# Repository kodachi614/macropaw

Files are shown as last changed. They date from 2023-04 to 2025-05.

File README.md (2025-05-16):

# MacroPaw Keypads

The MacroPaw keypads are a line of small yet fully-customizable mechanical
keyboards. (The name was originally from my son, years ago when he was young,
and the "paw" motif has kinda stuck.) The core of the MacroPaws is a Raspberry
Pi RP2040 with 16MiB of flash memory, a USB-C connector, and an attached key
matrix and RGB LEDs (which may or may not be under the keys). Some MacroPaws
have more capability than others; all are crazy customizable by writing Python
code. (Yes. Python. On a keyboard. It's insane and wonderful to live in the
future.)

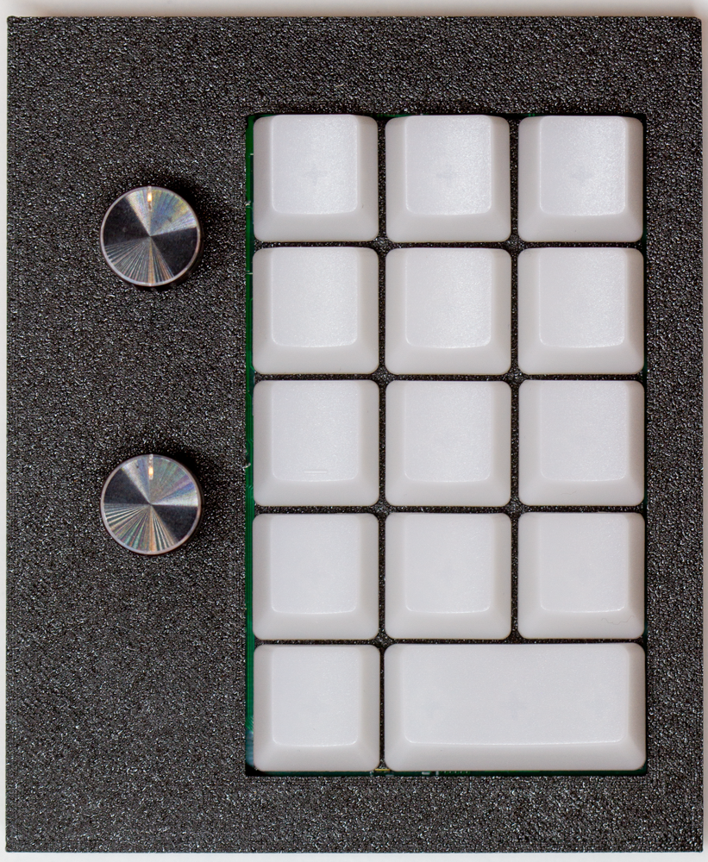
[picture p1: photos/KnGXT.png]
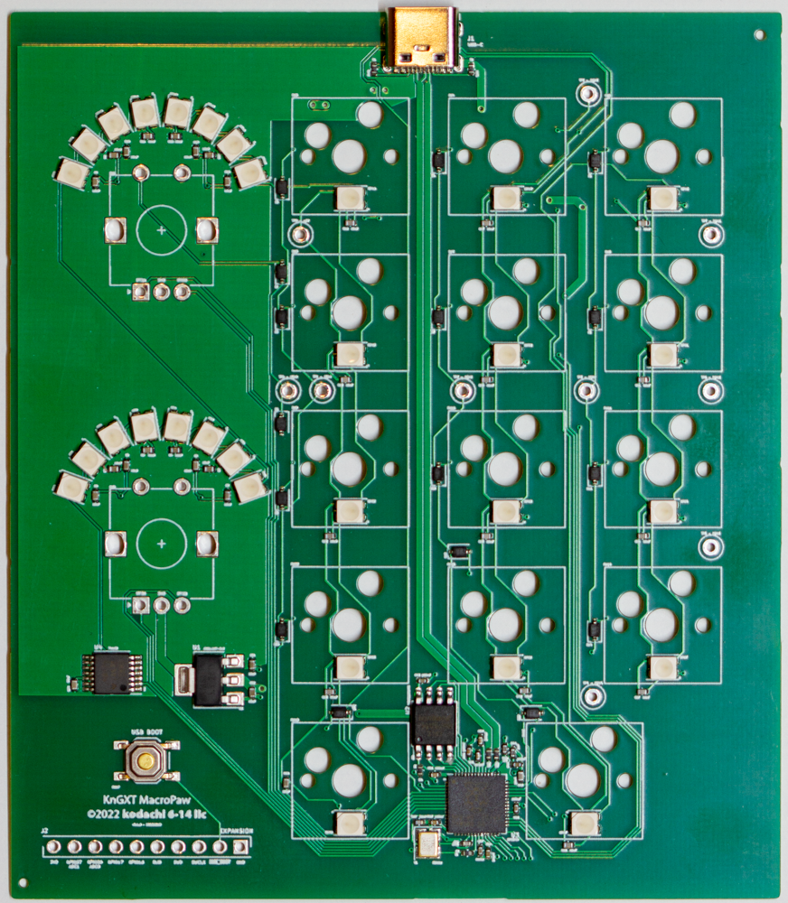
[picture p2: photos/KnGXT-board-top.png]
|  |  |
| :-: | :-: |
| _Assembled KnGXT_ | _KnGXT PCB_ |

Currently extant MacroPaw boards include:

| Board ID | Description |
| :-: | :- |
| KnGXT | Mostly a proof-of-concept for an RP2040-based USB HID: it has 14 hotswappable MX keyswitches in a 3x5 layout like a number pad (including one 2U key, which is why it's 14 instead of 15), two rotary encoders with pushbuttons, and a bunch of RGB LEDs under the encoders and keys. |
| KnGYT | Mostly a proof-of-concept for double-sided assembly. It has ten hotswappable MX keyswitches in a 5x2 grid, ten RGB LEDs under the keys, and no rotary encoders. It's _much_ smaller than its sibling the KnGXT, because most of the electronics are on the back of the board. |
| Beatboxer KnH0F | A single-sided embedded keyboard controller for use in a [custom life-sized drum machine]. It has 8 RGB LEDs on the front of the board for hardware test and debugging, and its key matrix is an 8x8 grid that's mechanically arranged as a 16x4 grid of arcade buttons. |

[custom life-sized drum machine]: https://sig.gy/bbox/

Both the firmware and the hardware of the MacroPaws are **open source**.

## Firmware

The firmware is licensed under the GNU General Public License, version 3.0 or
later.

The `firmware` directory within each board's directory includes the firmware
source code firmware and the firmware license (in `firmware/LICENSE`).

The MacroPaw firmware is based on the [KMK Firmware], and on Adafruit's
[CircuitPython] and the [NeoPixelBackground] class. See
[BUILDING.md](BUILDING.md) for details about how to build the firmware,
including information about the versions of CircuitPython and KMK that are
used and how to get them.

Of course, if you don't want to build your own, you can just grab prebuilt
firmware for the [MacroPaw KnGXT], [MacroPaw KnGYT], and [MacroPaw Beatboxer
KnH0F] boards.

[KMK Firmware]: https://github.com/KMKfw/kmk_firmware/
[CircuitPython]: https://circuitpython.org/
[NeoPixelBackground]: https://learn.adafruit.com/intro-to-rp2040-pio-with-circuitpython/advanced-using-pio-to-drive-neopixels-in-the-background
[MacroPaw KnGXT]: https://www.kodachi.com/firmware/macropaw-KnGXT.uf2
[MacroPaw KnGYT]: https://www.kodachi.com/firmware/macropaw-KnGYT.uf2
[MacroPaw Beatboxer KnH0F]: https://www.kodachi.com/firmware/macropaw-Beatboxer.uf2

## Hardware

The hardware is licensed under the CERN Open Hardware License, version 2.0
or higher, Strongly Reciprocal.

The `hardware` directory within each board's directory includes the [KiCad] 7
design files for the hardware, the fabrication outputs used for the official
production runs of the hardware, and of course the hardware license (in
`hardware/LICENSE`).

[KiCad]: https://www.kicad.org/

## 3D Models

The `models` directory within some boards' directories includes the 3D models
for cases, etc., for the board. Boards without a `models` directory haven't
had models made yet!

The models are also licensed under the CERN Open Hardware License, version 2.0
or higher, Strongly Reciprocal.

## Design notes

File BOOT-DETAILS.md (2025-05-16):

# Boot Details

What MacroPaws actually _run_ is CircuitPython; the MacroPaw firmware is
really a Python program being executed by the Python interpreter that's
started when the board boots.

## The Boot Process

The boot process for CircuitPython will probably seem familiar to anyone who
has worked with embedded systems, and incredibly alien to anyone who hasn't:

- First, the hardware does its cold-start routine. On embedded systems with
  flash memory (like the MacroPaw boards), this is usually some _very_
  bare-bones hardware initialization, followed by a jump to code that's been
  preloaded into the flash. In this case, that's CircuitPython.

- The CircuitPython boot code first sets up everything needed for the Python
  interpreter itself. Much of this is independent of the hardware it's running
  on (for example, initializing the interpreter's data structures) but some of
  it is hardware-specific (for example, setting up the console to use for the
  error output or a REPL).

- Once CircuitPython has the interpreter ready to go, it looks at a predefined
  location in flash to see if there's a FAT filesystem image there. If so,
  CircuitPython mounts it as `/`, then looks for `/boot.py`.  If that's
  present, it runs it. `/boot.py` gets to do certain special things that are
  hard to change in later code, but other than that it's a normal Python
  script.

- After `/boot.py` runs, CircuitPython looks for `/code.py` and runs that.
  This is the main program for the board, and in the case of a MacroPaw board,
  it's where the code that actually makes the board act like a keyboard lives.

**Note**: you can't use `mpy-cross` to precompile `/boot.py` or `/code.py`.

## USB

USB initialization deserves special mention here:

- The USB stack is part of CircuitPython (specifically, it's the [tinyusb]
  stack).

- During CircuitPython initialization, the `supervisor` object is created, and
  by default it is set up to enable a USB mass storage device and a USB serial
  device.

- One of the special things that `/boot.py` can do is modify the `supervisor`
  to _disable_ mass storage and USB serial -- and in fact, the MacroPaw
  `boot.py` normally disables both, since a MacroPaw board should usually appear as a keyboard, not a keyboard + disk + serial device!

  However, all MacroPaws have a (board-specific) way to enter "mass storage
  mode" where `/boot.py` will permit them to stay enabled. This allows easier
  debugging (you can see errors that get thrown, and you can modify code by
  editing files on the mass storage device).

- **After `/boot.py` completes**, CircuitPython looks at the `supervisor`
  object and configures the USB stack to present the devices that are enabled.
  They can't be disabled after this initialization step, which is why
  `/boot.py` needs to be where the MacroPaws decide whether or not special
  boot modes are in play.

- More USB devices _can_ be added after `/boot.py` completes, and KMK uses
  this capability to configure the USB stack to appear as a USB HID, in
  addition to whatever other devices were already enabled. This is the part
  that makes the board actually look like a keyboard.

- Finally, every USB device has to have a vendor ID and a product ID.
  MacroPaws use vendor ID 0x1209 and a product IDs obtained from
  https://pid.codes/.

[tinyusb]: https://docs.tinyusb.org/en/latest/index.html

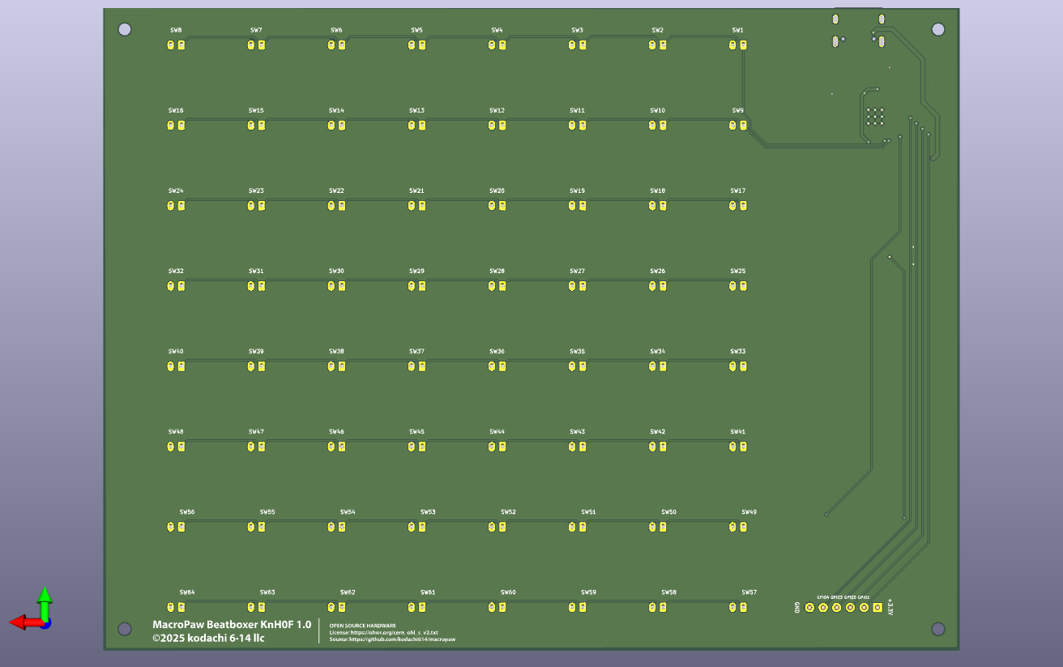
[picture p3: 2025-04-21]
Beatboxer/renders/Bottom (ortho).png

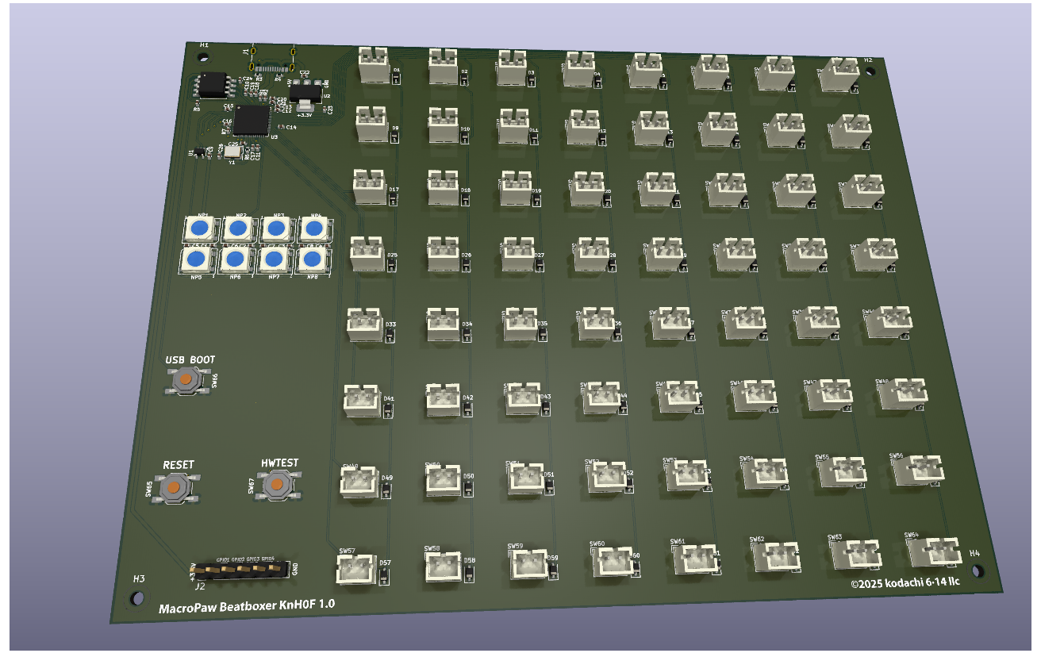
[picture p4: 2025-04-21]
Beatboxer/renders/Top (raytraced).png

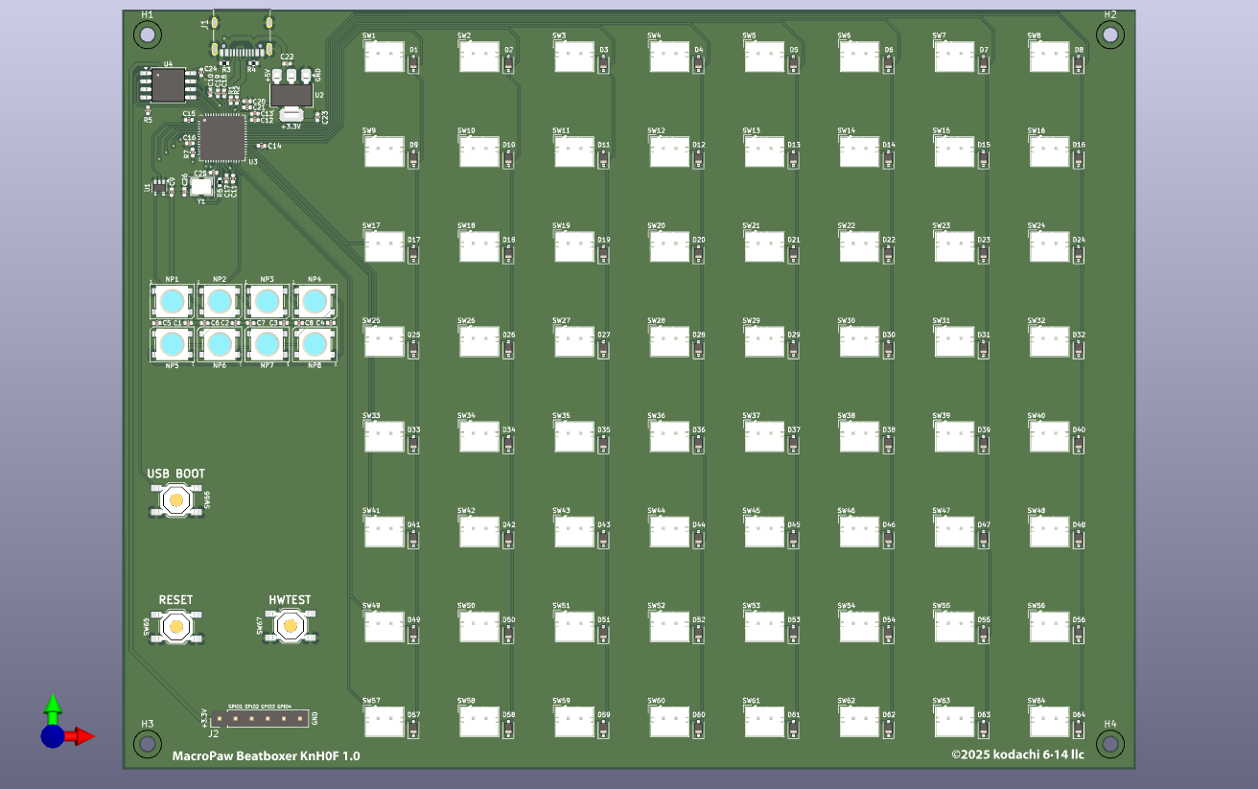
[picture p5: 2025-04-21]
Beatboxer/renders/Top (ortho).png

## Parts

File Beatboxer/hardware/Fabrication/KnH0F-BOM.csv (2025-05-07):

Comment | Designator | Footprint | LCSC Part Number
10uF | C1,C2,C3,C4,C5,C6,C7,C8,C9,C22,C23,C24 | 0402 | C15525
100nF | C10,C11,C12,C13,C14,C15,C16,C17,C18,C19 | 0402 | C1525
1uF | C20,C21 | 0402 | C52923
30pF | C25,C26 | 0402 | C1570
1N4148 | D1,D2,D3,D4,D5,D6,D7,D8,D9,D10,D11,D12,D13,D14,D15,D16,D17,D18,D19,D20,D21,D22,D23,D24,D25,D26,D27,D28,D29,D30,D31,D32,D33,D34,D35,D36,D37,D38,D39,D40,D41,D42,D43,D44,D45,D46,D47,D48,D49,D50,D51,D52,D53,D54,D55,D56,D57,D58,D59,D60,D61,D62,D63,D64 | SOD-323 | C2128
USB_C_Receptacle_USB2.0_16P | J1 | USB_C_Receptacle_Palconn_UTC16-G | C165948
WS2812B | NP1,NP2,NP3,NP4,NP5,NP6,NP7,NP8 | PLCC4 5.0x5.0mm | C2761795
27 | R1,R2 | 0402 | C25100
5.1k | R3,R4 | 0402 | C25905
1k | R5,R7 | 0402 | C11702
1k | R6 | 0402 | C11702
SW_Push_45deg | SW1,SW2,SW3,SW4,SW5,SW6,SW7,SW8,SW9,SW10,SW11,SW12,SW13,SW14,SW15,SW16,SW17,SW18,SW19,SW20,SW21,SW22,SW23,SW24,SW25,SW26,SW27,SW28,SW29,SW30,SW31,SW32,SW33,SW34,SW35,SW36,SW37,SW38,SW39,SW40,SW41,SW42,SW43,SW44,SW45,SW46,SW47,SW48,SW49,SW50,SW51,SW52,SW53,SW54,SW55,SW56,SW57,SW58,SW59,SW60,SW61,SW62,SW63,SW64 | JST PH B2B-PH-K 1x02 P2.00mm Vertical | C131337
SW_Push | SW65,SW66,SW67 | SPST_TL3342 | C318884
74AHC1G125 | U1 | SOT-353 | C151417
AMS1117-3.3 | U2 | SOT-223 | C6186
RP2040 | U3 | QFN-56 | C2040
W25Q128JVS | U4 | SOIC-8 5.3x5.3mm P1.27mm | C97521
12MHz | Y1 | SMD_3225 | C9002

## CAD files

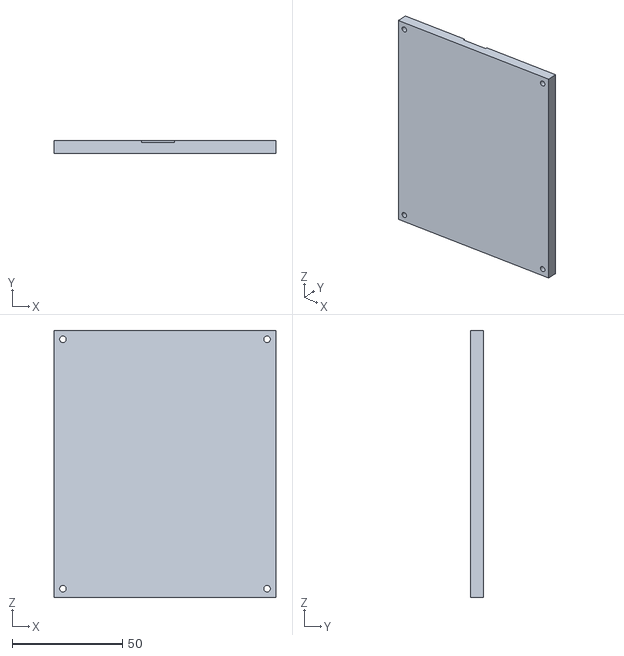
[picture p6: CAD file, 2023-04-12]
KnGXT/models/Case Bottom.stl
100.5 x 6.00 x 121.0

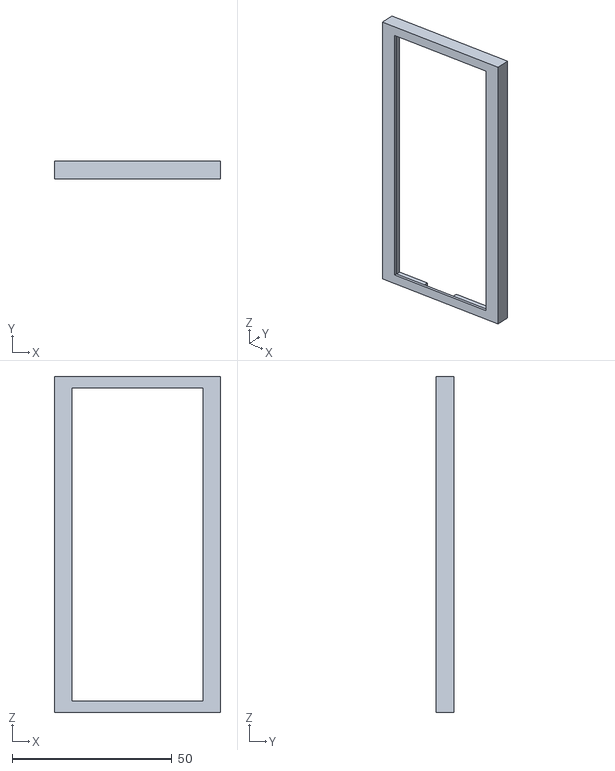
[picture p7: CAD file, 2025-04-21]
KnGYT/models/Top.stl
52.1 x 5.50 x 105.2

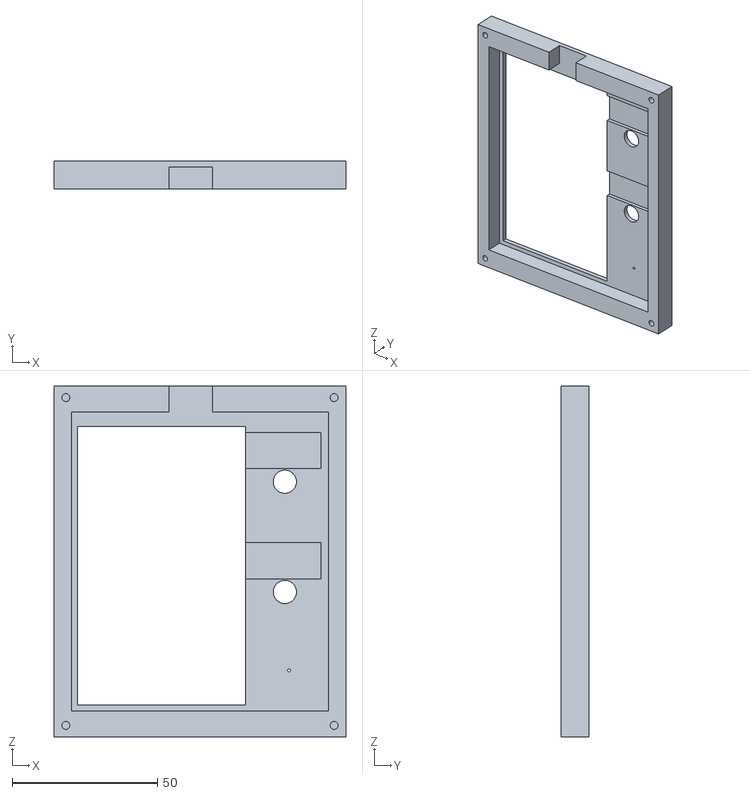
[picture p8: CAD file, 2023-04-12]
KnGXT/models/Case Top with Boot Hole.stl
100.5 x 9.50 x 121.0

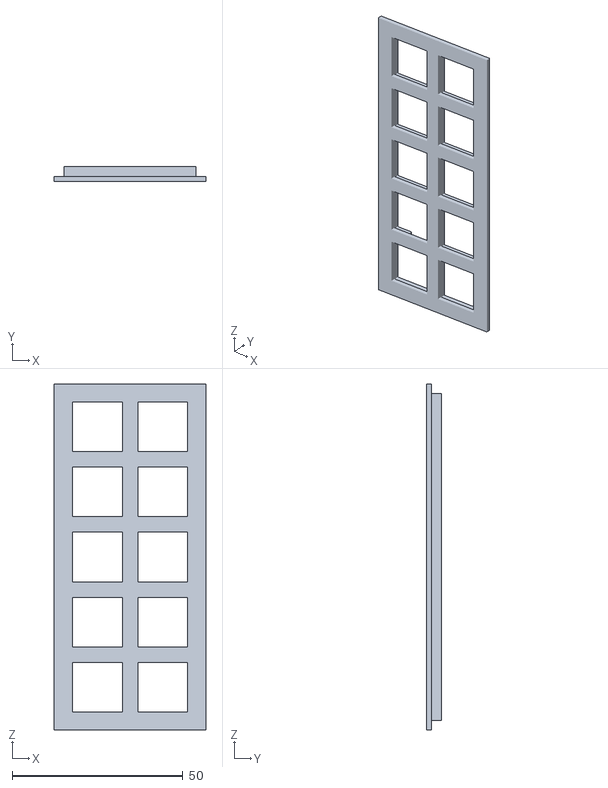
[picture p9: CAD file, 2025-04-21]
KnGYT/models/Plate.stl
44.4 x 4.50 x 101.2

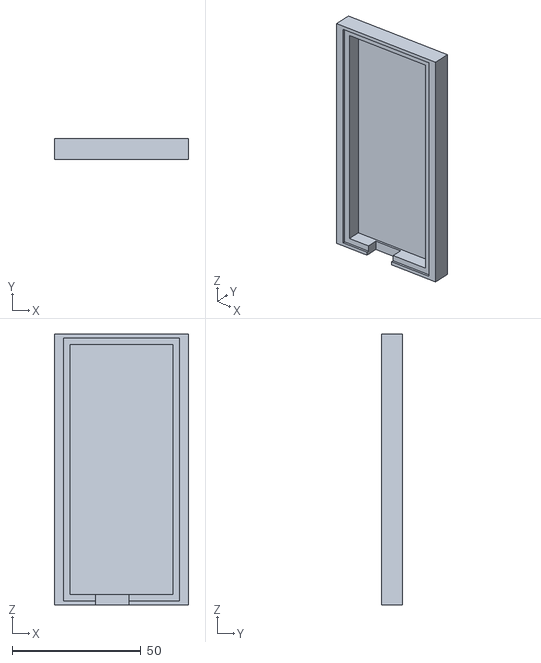
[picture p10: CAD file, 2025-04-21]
KnGYT/models/Bottom.stl
52.1 x 8.00 x 105.2

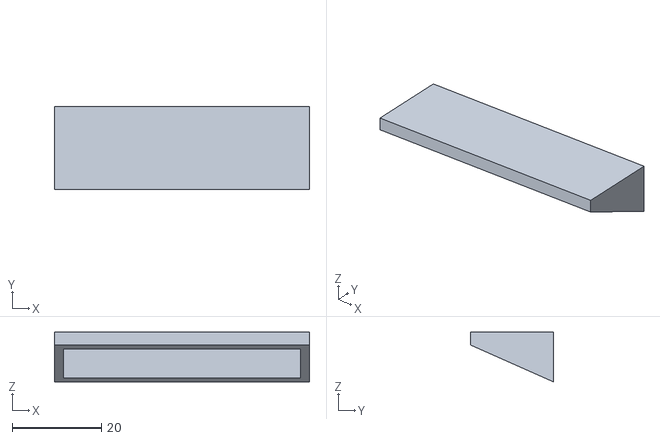
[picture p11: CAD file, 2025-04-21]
KnGYT/models/End Cap.stl
57.1 x 18.5 x 11.1

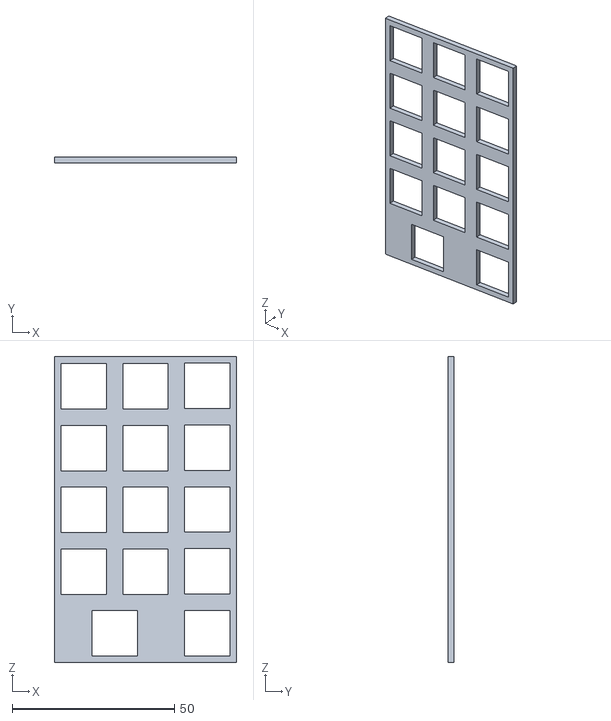
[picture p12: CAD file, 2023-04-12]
KnGXT/models/Switch Plate 2mm.stl
56.1 x 2.00 x 94.2

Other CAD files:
KnGXT/models/Case Top.stl
KnGXT/models/Case Top with Boot Button.stl
KnGXT/models/MacroPaw KnGXT.f3d

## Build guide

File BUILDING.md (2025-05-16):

# Building

This document describes how to build the MacroPaw firmware from source. This
should Just Work on MacOS and Linux; it probably has a fighting chance with
WSL2 on Windows, but that's untested.

If you're just trying to flash a MacroPaw board, you probably don't need this
document: check out the [README.md](README.md) or maybe the [User
Guide](USERGUIDE.md) instead.

## Overview

When a MacroPaw board boots, what's actually getting booted is
[CircuitPython]; in turn, CircuitPython loads up the MacroPaw's `boot.py` and
`code.py` files to make things actually happen.
([BOOT-DETAILS.md](BOOT-DETAILS.md) has a lot more detail on this.)

Given all of this, to build the firmware for a MacroPaw board you must:

1. Have a working CircuitPython base image. This is the CircuitPython code with
   board-specific support code, but nothing about KMK or the MacroPaw code
   itself: it's just CircuitPython. Loading the base image onto a MacroPaw
   board will give you the ability to run Python code, but it won't give you a
   working keyboard.

   **You don't have to build this yourself** unless you need to change it. The
   build process knows how to fetch a prebuilt version for you.

2. Have a working KMK base image. This is the CircuitPython code that provides
   the ability for a board to act like a USB HID keyboard. This is the only
   piece of the firmware that isn't board-specific.

   **You don't have to build this yourself** unless you need to change it. The
   build process knows how to fetch a prebuilt version for you.

3. Take the MacroPaw code and the KMK code, load them into a FAT filesystem
   image, and then combine that with the base CircuitPython image so that
   CircuitPython finds the FAT with the MacroPaw code when it boots.

The output of this process is a single .UF2 file that you can flash to your
MacroPaw board. The Makefile here knows how to do all of this, but the real
magic mostly happens in `tools/build-uf2` and `tools/flash`.

**This is version 0.5.2 of the MacroPaw firmware.** It is based on

- CircuitPython 9.2.7 built from commit `a87b74cd54` on the
  `flynn/kodachi-ports-9.2.7` branch of
  [kodachi614/circuitpython](https://github.com/kodachi614/circuitpython)

- KMK built from commit `e176c41b1d` on the `flynn/dev/macropaw-2` branch of
  [kodachi614/kmk_firmware](https://github.com/kodachi614/kmk_firmware)

Again, **you do not have to build either of these yourself.** The build
process knows how to fetch prebuilt versions from
<https://www.kodachi.com/firmware> for you; you only _need_ to build them
yourself if you're trying to make changes in them.

[KMK Firmware]: https://github.com/KMKfw/kmk_firmware/
[CircuitPython]: https://circuitpython.org/

## Tools You'll Need

- Python 3.10 or later

   On MacOS, you can use `brew install python` for this: the system Python is
   not likely to work.

- `mkfs.vfat`

   Part of the build process involves creating a FAT filesystem image; to do
   that, we need `mkfs.vfat`. On MacOS, get this with `brew install
   dosfstools` (and make sure that `/opt/homebrew/sbin` is in your `PATH`).

- GNU `make`

   Install GNU `make` on MacOS with `brew install make` and use that (it'll
   install as `gmake`). The Makefile here won't work with the system `make`.

- `mpy-cross`

   Finally, in a perfect world you'll have `mpy-cross` somewhere on your
   `PATH`. `mpy-cross` is a tool from CircuitPython that reads .py files and
   outputs `.mpy` files, which contain Python bytecode: this is a win because
   it lets CircuitPython just load the bytecode instead of having to parse the
   Python source at boot time. On a KnGXT, this cuts startup time from about
   three seconds to under half a second.

   At the moment, the only way to get `mpy-cross` is to build CircuitPython.
   There are [great directions for this] but it would be lovely if there were
   an easier way. **If you build `mpy-cross`, pay attention to the version of
   CircuitPython you use.** You **must** use the same version of CircuitPython
   that the MacroPaw firmware is built with.

[great directions for this]: https://docs.circuitpython.org/en/latest/BUILDING.html

## The Basic Build Process

Given the prerequisites above, just clone this repo and run `make` on a Mac or
Linux box. You'll get a bunch of `macropaw-$boardID.uf2` files in the root of
the repo.

To make a single board, run `make $boardID` instead. For example, to build
just the firmware for the KnGXT, run `make KnGXT`.

### Testing Tweaks

If you're actively testing tweaks to the MacroPaw code itself, don't bother
constantly rebuilding the code. Instead, check your board to find out how to
get it into mass storage mode, where it'll show up as a mountable USB drive.
In that mode, you can just copy the new code over to the board and it'll
automagically reboot into your new code. It will also present a serial port in
this mode, which you'll definitely want to connect to so you can see debug
logs, error reports, etc.

Of course, when you're done testing, you'll probably be best off building a
new firmware UF2 to flash to the board. This is especially true if you want to
distribute the firmware to others, or if you want to make sure that the
firmware is in a known-good state.

## The Complete Build Process

So... what if you _do_ want to add support for a new kind of MacroPaw board,
or you want to upgrade KMK? Three repos work together for this:
`kodachi614/circuitpython`, `kodachi614/kmk_firmware`, and
`kodachi614/macropaw`:

1. `kodachi614/circuitpython` is what you'll use to build the CircuitPython
   base image. This is the CircuitPython code with board-specific support
   code, but nothing about KMK or the MacroPaw code itself.

2. `kodachi614/kmk_firmware` is what you'll use to get the KMK base tarfile.
   This is CircuitPython code that provides the ability for a board to act
   like a USB HID keyboard. This is the only piece of the firmware that isn't
   board-specific.

3. Finally, `kodachi614/macropaw` (this repo) is the MacroPaw code itself.
   This is CircuitPython code that uses KMK to make a MacroPaw board act like
   a MacroPaw: it defines the keymap, how the LEDs get handled, and so on.

**Note: Firmware is board-specific.**

You'll be building firmware _for a specific board_. We'll show how to build
for the MacroPaw KnGXT here.

Again, **you don't need to do this if you're only touching the MacroPaw files
in this repository**. If that's you, go up to the "The Basic Build Process"
section.

### 1. The CircuitPython Base Image

Remember that **the CircuitPython base image is board-specific** because it
contains information about which specific pins on the RP2040 are used for
which functions. Every board has its own base image.

In the `kodachi614/circuitpython` repo, you'll find board definitions for each
MacroPaw. To build the base image for a KnGXT:

- `cd ports/raspberrypi` in your clone of `kodachi614/circuitpython`
- `make BOARD=kodachi_macropaw_kngxt clean`
- `make BOARD=kodachi_macropaw_kngxt`

The built base image will be in `build-kodachi_macropaw_kngxt/firmware.uf2`.
Copy that into `tools/base-firmware-KnGXT.uf2` in your clone of
`kodachi614/macropaw` for later use.

(If you don't have a `base-firmware-KnGXT.uf2` file in your `macropaw/tools`
directory, the build process will pull it from
<http://www.kodachi.com/firmware/circuitpython-kodachi-$version-g$commit-$boardID>
where `$version` and `$commit` have defaults set in the Makefile, and
`$boardID` is e.g. `KnGXT`.)

### 2. The KMK Base Tarfile

Given the CircuitPython base image, you next need the KMK firmware. This is
the CircuitPython code that provides the ability for a board to act like a USB
HID keyboard. This is the only piece of the firmware that isn't
board-specific.

From the `kodachi614/kmkfw` repo, just run `MOUNTPOINT=/tmp make tar` to tar
up everything you need into `kmk-$SHA.tgz`. Copy that into
`macropaw/tools` without changing its name.

(If you don't have a `kmk-$SHA.tgz` file in your `macropaw/tools` directory,
the build process will pull it from
<http://www.kodachi.com/firmware/kmk-$SHA.tgz> where, again, `$SHA` has a
default set by the Makefile.)

### 3. The MacroPaw Code

Finally, you need the MacroPaw code itself. This is CircuitPython code that
uses KMK to make a MacroPaw board act like a MacroPaw: it defines the
keymap, how the LEDs get handled, and so on.

To build the MacroPaw code after you have the base image and the KMK tarfile,
just go to the top level of your clone of the `kodachi614/macropaw` repo and run
`make`. This will build firmware for all supported boards and leave the
resulting UF2 images in `macropaw-$boardID.uf2` files in the root of the repo.

To build just the firmware for a single board, run `make $boardID` instead.
For example, to build just the firmware for the KnGXT, run `make KnGXT`.

## Flashing the Firmware

To flash the firmware, put the MacroPaw board into bootloader mode. How you do
this depends on the board you have, but it's generally a matter of holding
down some BOOT button while plugging it into your computer. Once it's in
bootloader mode, it should show up as a USB drive called "RPI_RP2".

Once you have `RPI_RP2` mounted, run `tools/flash $boardID` (e.g. `tools/flash
KnGXT`). This will erase your board, then flash your board with
`macropaw-$boardID.uf2` (and note that `$boardID` can be kind of fluid, so if
you have a `macropaw-KnGXT-v0.5.0.uf2` for some reason, you could `tools/flash
KnGXT-v0.5.0`).

During the flashing process, you'll see status for what's going on, and on
MacOS you'll also see complaints about `RPI_RP2` being disconnected without
being properly ejected. **This is normal**; there's just no way to get the
disk ejected in time while the board is being flashed.

Once flashing is complete, your board will reboot into its hardware test mode;
follow the directions for your board to complete the hardware test and have it
reboot into being a keyboard!

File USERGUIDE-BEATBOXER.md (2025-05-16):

# MacroPaw User Guide

The MacroPaw keypads are a line of small yet fully-customizable mechanical
keyboards. (The name was originally from my son, years ago when he was young,
and the "paw" motif has kinda stuck.) The core of the MacroPaws is a Raspberry
Pi RP2040 with 16MiB of flash memory, a USB-C connector, and an attached key
matrix and RGB LEDs (which may or may not be under the keys). Some MacroPaws
have more capability than others; all are crazy customizable by writing Python
code. (Yes. Python. On a keyboard. It's insane and wonderful to live in the
future.)

This guide covers the MacroPaw Beatboxer KnH0F board. There is a [separate
guide] for the MacroPaw KnGXT and KnGYT boards.

[separate guide]: USERGUIDE.md

## Overview

The MacroPaw Beatboxer KnH0F has 8 RGB LEDs on the front of the board, for
debugging, and an 8x8 key matrix that's normally mechanically set up as a 16x4
grid of arcade buttons. It also has three small buttons on the front of the board: `USB BOOT`, `HWTEST`, and `RESET`.

The default firmware (available at https://www.kodachi.com/firmware) for both
boards supports a normal keyboard mode in which each of the 8x8 grid of
buttons sends a separate USB key, a hardware test mode to make sure everything
is working, and of course the ability to fully reprogram the firmware.

## Normal Operation

After a MacroPaw Beatboxer KnH0F has been flashed and tested, when you plug it
in it will act like a keyboard. The default firmware uses the following
layout:

| Col 1 | Col 2 | Col 3 | Col 4 | Col 5 | Col 6 | Col 7 | Col 8 |
| :-: | :-: | :-: | :-: | :-: | :-: | :-: | :-: |
| a | b | c | d | e | f | g | h |
| i | j | k | l | m | n | o | p |
| q | r | s | t | u | v | w | x |
| A | B | C | D | E | F | G | H |
| I | J | K | L | M | N | O | P |
| Q | R | S | T | U | V | W | X |
| 0 | 1 | 2 | 3 | 4 | 5 | 6 | 7 |
| - | = | . | , | / | ; | space | enter |

## Special Operation Modes

### First Use

The very first time a MacroPaw is booted, it will launch in USB Boot mode to
be flashed with new firmware. See the [Flashing](#flashing) section below for
details on how to do this.

### Flashing

To flash the firmware, the MacroPaw must be in USB Boot mode, where it will appear as a USB Mass Storage device called `RPI-RP2`. The first time a MacroPaw is booted, it will automatically enter USB Boot mode. If you need to reenter USB Boot mode, hold down the `USB BOOT` button while either plugging in the MacroPaw or pressing the `RESET`.

You can flash new firmware in this mode by copying a `macropaw-Beatboxer.uf2` file to the `RPI-RPI2` volume. This may take 30-60 seconds; this is normal. After flashing, the `RPI-RPI2` volume will disappear, and the MacroPaw will reboot into hardware test mode.

### Hardware Test Mode

In hardware test mode, the MacroPaw will _not_ act like a keyboard. It first
light all the LEDs in red, then green, then blue, then dim white. After that,
it will turn off the LEDs and starting monitoring key presses. For each key
press, it will light the LED for that key's row in red, and for that key's
column in blue (keys on the diagonal will led a single LED in purple, since
the same LED will be lit both red and blue).

Once all the keys have been pressed, the LEDs will flash green and the board will reboot into normal operation, as a keyboard. (If the LEDs light red, there is a problem.)

To reenter hardware test mode later, hold the `HWTEST` button while either
plugging in the MacroPaw or pressing the `RESET` button. The MacroPaw will show a countdown on the LEDs; keep holding the `HWTEST` button until the countdown is over, then let go. The board will reboot into hardware test mode.

## Resetting

To reset a Beatboxer board, either unplug and replug it, or hold the RESET
button for a second or two, then let go. When you let go, the board will
reset.

## Mass Storage Mode

To enter mass storage mode - where the MacroPaw will appear as a USB mass
storage device called `BEATBOX`, and you can edit the firmware files live -
hold down the `HWTEST` button while plugging in the MacroPaw or pressing the
`RESET` button. The board will show a countdown on the LEDs; let go before the
countdown ends, and the board will reboot into mass storage mode.

### Serial Debugging

While the mass storage device is present (see above), the MacroPaw will also
present a USB-serial interface that you can use as a CircuitPython console.

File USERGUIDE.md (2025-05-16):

# MacroPaw User Guide

The MacroPaw keypads are a line of small yet fully-customizable mechanical
keyboards. (The name was originally from my son, years ago when he was young,
and the "paw" motif has kinda stuck.) The core of the MacroPaws is a Raspberry
Pi RP2040 with 16MiB of flash memory, a USB-C connector, and an attached key
matrix and RGB LEDs (which may or may not be under the keys). Some MacroPaws
have more capability than others; all are crazy customizable by writing Python
code. (Yes. Python. On a keyboard. It's insane and wonderful to live in the
future.)

This guide covers the MacroPaw KnGXT and KnGYT boards. There is a [separate
guide] for the MacroPaw Beatboxer KnH0F board.

[separate guide]: USERGUIDE-BEATBOXER.md

## Overview

| Name  | Keys | Layout | Rotary Encoders |
| :---- | :--: | :----: | :--- |
| KnGXT |  14  | 3x5 | 2 |
| KnGYT |  10  | 5x2 | 0 |

The default firmware (available at https://www.kodachi.com/firmware) supports
multiple layers for a variety of different control functions, a hardware test
mode, and the ability to fully reprogram the firmware.

## Using the Default Firmware

Using the default firmware, both the KnGXT and KnGYT support:

- A main layer which (mostly) sends function keys
- A DaVinci Resolve control-surface layer
- A meta layer which allows switching various MacroPaw settings

On the KnGXT, the default firmware also supports a number-pad layer, and media
control on the main layer and the number-pad layer.

On the KnGYT, the meta layer supports media control.

On both models, keys marked "X or Y" performs X when tapped and Y when held.
So, for example, both models of MacroPad have a key in the lower-right corner
which, on the Main layer, sends F14 when tapped, and switches to the Meta
layer as long as it is held.

### KnGXT layout

All MacroPaws boot into the Main layer.

#### Main Layer

Encoders:
| CCW  | Button | CW |
| :--: | :--: | :--: |
| Vol down | Mute | Vol Up |
| << | Play/Pause | >> |

Keys:
| Col 1 | Col 2 | Col 3 |
| :---: | :---: | :---: |
| F1 | F2 | F3 |
| F4 | F5 | F6 |
| F7 | F8 | F9 |
| F10 | SPACE | ENTER |
| F13 | F14 or meta layer |

The Main layer includes SPACE and ENTER to make it easier to drive slide shows
and [`demosh`](https://github.com/BuoyantIO/demosh).

#### DaVinci Resolve Layer

Encoders:
| CCW  | Button | CW |
| :--: | :--: | :--: |
| Prev Mark | Mark | Next Mark |
| Reverse | Play/Pause | Forward |

Keys:
| Col 1 | Col 2 | Col 3 |
| :---: | :---: | :---: |
| Prev Edit | Mark | Next Edit |
| Razor | Ripple Delete | Cut |
| Prev Frame | Mark In | Next Frame |
| Undo | Mark Out | Redo |
| -- | Save or meta layer |

#### Numpad layer

Encoders:
| CCW  | Button | CW |
| :--: | :--: | :--: |
| Vol down | Mute | Vol Up |
| << | Play/Pause | >> |

Keys:
| Col 1 | Col 2 | Col 3 |
| :---: | :---: | :---: |
| 7 or ( | 8 or BSPC | 9 or ) |
| 4 | 5 | 6 |
| 1 | 2 | 3 |
| . or =| 0 | * or / |
| + or - | Enter or meta layer |

#### Meta Layer

The Meta layer allows switching layers and switching the keypad to match
the keymap used by the OS.

Encoders:
| CCW  | Button | CW |
| :--: | :--: | :--: |
| -- | -- | -- |
| -- | -- | -- |

Keys:
| Col 1 | Col 2 | Col 3 |
| :---: | :---: | :---: |
| Switch to QWERTY | -- | Switch to Dvorak |
| -- | -- | -- |
| -- | -- | -- |
| Da Vinci Resolve | Numpad | -- |
| Main | -- |

### KnGYT layout

All MacroPaws boot into the Main layer.

#### Main layer

| Col 1 | Col 2 | Col 3 | Col 4 | Col 5 |
| :---: | :---: | :---: | :---: | :---: |
| F1 | F2 | F3 | F4 | F5 |
| F10 | SPACE | ENTER | F13 | F14 or meta layer |

The Main layer includes SPACE and ENTER to make it easier to drive slide shows
and [`demosh`](https://github.com/BuoyantIO/demosh). The second row picks up
with F10 to better match the KnGXT's Main layer.

#### Da Vinci Resolve Layer

| Col 1 | Col 2 | Col 3 | Col 4 | Col 5 |
| :---: | :---: | :---: | :---: | :---: |
| Prev Frame or Edit | Prev Mark | Mark | Next Mark | Next Frame or Edit |
| Razor or Ripple Delete | Reverse or Undo | Play/Pause | Forward or Redo | Save or meta layer |

#### Meta Layer

The Meta layer allows media control, switching layers, and switching the
keypad to match the keymap used by the OS.

| Col 1 | Col 2 | Col 3 | Col 4 | Col 5 |
| :---: | :---: | :---: | :---: | :---: |
| Vol Up | Main | Da Vinci Resolve | Switch to QWERTY | Switch to Dvorak |
| Vol Down | Prev Track | Play/Pause | Next Track | -- |

## Resetting the MacroPaw

To reset a KnGXT, unplug it and plug it back in.

To reset a KnGYT, there is a RESET button which you can press (gently) through
the case. If you turn the KnGYT upside down, you'll see the area to press: the
RESET button is closest to the USB connector.

## Updating the Firmware

To update the firmware, hold down the left and right keys on the topmost row
when plugging in the MacroPaw (or pressing the RESET button on a KnGYT). The
board will appear as a USB Mass Storage device named MACROPAW; you can edit or
replace the firmware files as desired.

### Serial Debugging

While the mass storage device is present (see above), the MacroPaw will also
present a USB-serial interface that you can use as a CircuitPython console.

## Hardware Test Mode

To reenter hardware test mode, hold down the left and right keys on the
bottommost row when plugging in the MacroPaw (or pressing the RESET button on
a KnGYT). For more details about hardware test mode, see the Assembly Guide
([ASSEMBLY-KnGXT.md](ASSEMBLY-KnGXT.md) or
[ASSEMBLY-KnGYT.md](ASSEMBLY-KnGYT.md))

## USB Boot Mode

Hold down the BOOT button while plugging in the MacroPaw (or pressing the
RESET button on a KnGYT). The MacroPaw will appear as a USB Mass Storage
device named `RPI-RP2`, and you can copy a `.uf2` file onto it to completely
replace the firmware. For more details, see the Assembly Guide
([ASSEMBLY-KnGXT.md](ASSEMBLY-KnGXT.md) or
[ASSEMBLY-KnGYT.md](ASSEMBLY-KnGYT.md))

You can press the BOOT button (gently) through the case -- you'll feel the
button click. On the KnGXT, the button is below and to the left of the bottom rotary encoder. On the KnGYT you'll be able to see
the area to press on the bottom of the case: the BOOT button is furthest from
the USB connector.

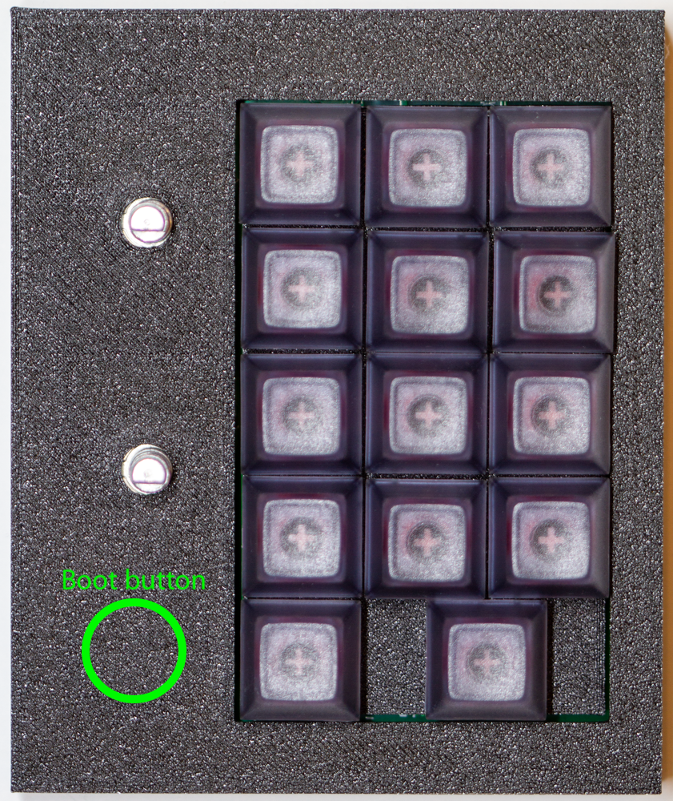
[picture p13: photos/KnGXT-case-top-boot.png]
|  |
| :-: |
| _Location of KnGXT boot button_ |

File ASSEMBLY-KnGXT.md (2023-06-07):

# MacroPaw KnGXT Assembly Guide

|  |  |
| :-: | :-: |
| _Assembled KnGXT_ | _KnGXT PCB_ |

The MacroPaw KnGXT was produced as a partly-assembled two-sided PCB board: all
the surface-mount components were installed at the factory, but quite a bit
was still left to be done:

- Factory reset (optional with a new board)
- Install firmware
- Basic hardware test
- Install hotswap sockets
- Install rotary encoders
- Install switches
- Full hardware test
- Install into case

## Factory Reset

To completely reset a KnGXT to new-out-of-the-factory condition, you need to
wipe its onboard flash memory. **WARNING: this will, of course, erase any
customization you've done.**

1. Grab David Welch's `flash_nuke.uf2` from
   https://github.com/dwelch67/raspberrypi-pico. This is a minimal RP2040
   program to completely wipe the attached flash.

   ```bash
   curl -o /tmp/flash_nuke.uf2 https://github.com/dwelch67/raspberrypi-pico/raw/main/flash_nuke.uf2
   ```

2. Hold down the USB_BOOT button on the MacroPaw KnGXT board and plug it into
   your computer with a USB-C cable.

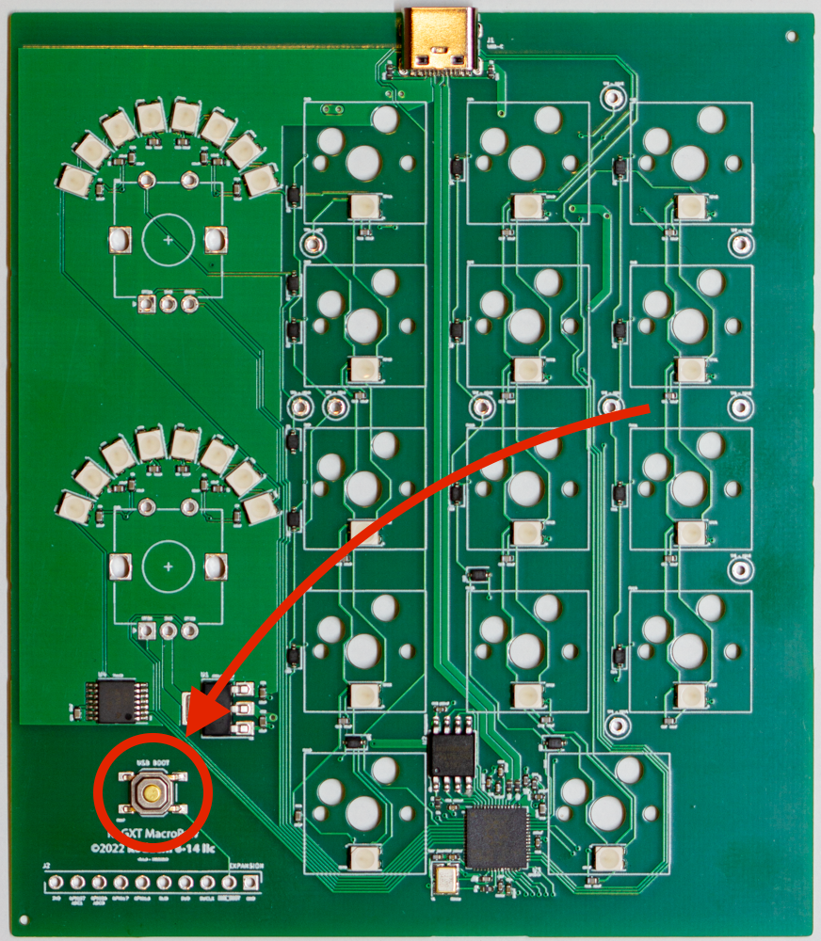
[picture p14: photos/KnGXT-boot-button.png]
    

3. The KnGXT should appear as a USB Mass Storage device named `RPI_RP2` on
   your computer.

4. Copy `flash_nuke.uf2` to the `RPI_RP2` volume. Note that with MacOS Ventura and
   later, the Finder won't work for this: use `cp` from a shell window instead.

   ```bash
   cp /tmp/flash_nuke.uf2 /Volumes/RPI_RP2
   ```

5. The `RPI_RP2` volume will vanish while `flash_nuke` runs, then return once it's done.

## Install Firmware

1. Grab the most recent MacroPaw KnGXT firmware from www.kodachi.com:

   ```bash
   curl -o /tmp/macropaw-KnGXT.uf2 https://www.kodachi.com/firmware/macropaw-KnGXT.uf2
   ```

   (Alternately, you can build your own firmware: follow the docs in [BUILDING.md].)

2. If your KnGXT doesn't already show up as the `RPI_RP2` volume, hold down
   the USB_BOOT button on the MacroPaw KnGXT board and plug it into your
   computer with a USB-C cable. The KnGXT should appear as a USB Mass Storage
   device named `RPI_RP2` on your computer.

    

3. Copy the firmware to the `RPI_RP2` volume. Note that with MacOS Ventura and
   later, the Finder won't work for this: use `cp` from a shell window instead.

   ```bash
   cp /tmp/macropaw-KnGXT.uf2 /Volumes/RPI_RP2
   ```

   **This step can take awhile.** 30-60 seconds is not unusual.

4. Wait for the KnGXT to reboot into hardware test mode. If this is a bare
   board, proceed to "Basic Hardware Test" below; if fully assembled, continue
   to "Full Hardware Test".

## Basic Hardware Test

The first time a MacroPaw is booted after new firmware is installed, it will
launch in _hardware test mode_. This mode doesn't function as a keyboard:
instead, it lets you verify that the LEDs, keyswitches, and rotary encoders on
the board work.

When booting in hardware test mode, all the lights will flash yellow at
startup. The LEDs should then cycle through red, green, and blue, then end up
all at a dim white.

When testing a board with no switches or encoders, this is as far as you can
reasonably go. Unplug the MacroPaw to continue to installing the hotswap sockets.

## Install Hotswap Sockets

Flip the board over to solder all 14 hotswap sockets on from the back of the
board. They'll only fit in one orientation, and they're fairly straightforward
to solder.

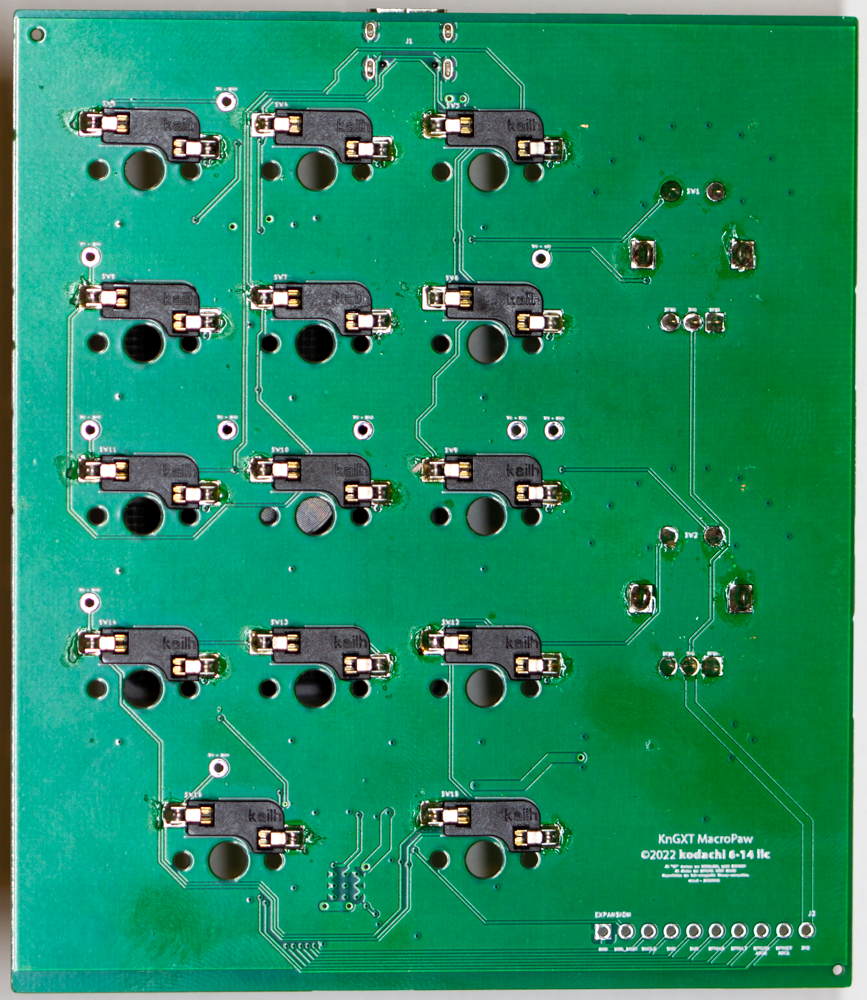
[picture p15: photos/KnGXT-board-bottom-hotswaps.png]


## Install Rotary Encoders

The KnGXT takes two EC11 rotary encoders where the shaft contains a
pushbutton. Insert these from the front of the board and solder them from the
back. Make certain to keep them straight when soldering! If you let them slant
much, you won't be able to get the case on.

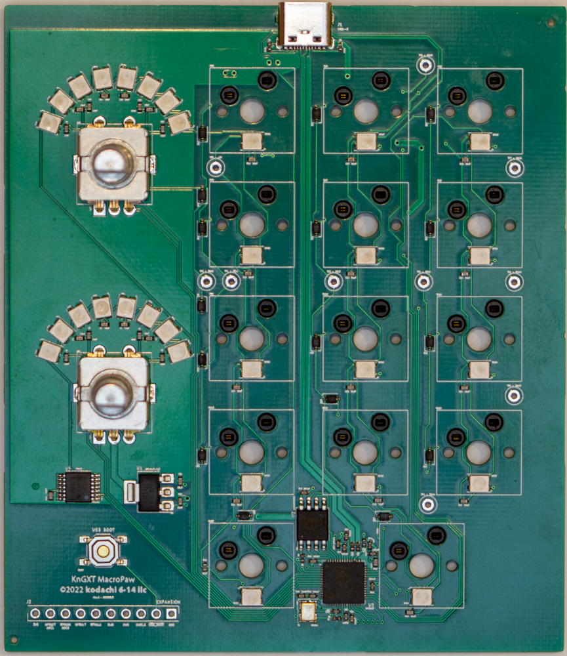
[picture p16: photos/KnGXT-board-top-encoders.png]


## Install Switches

The easiest way to install the switches into a KnGXT is actually to start by
plugging all the switches into the switch plate (since the plate doesn't have
standoffs, it's just there to support the keyswitches laterally):

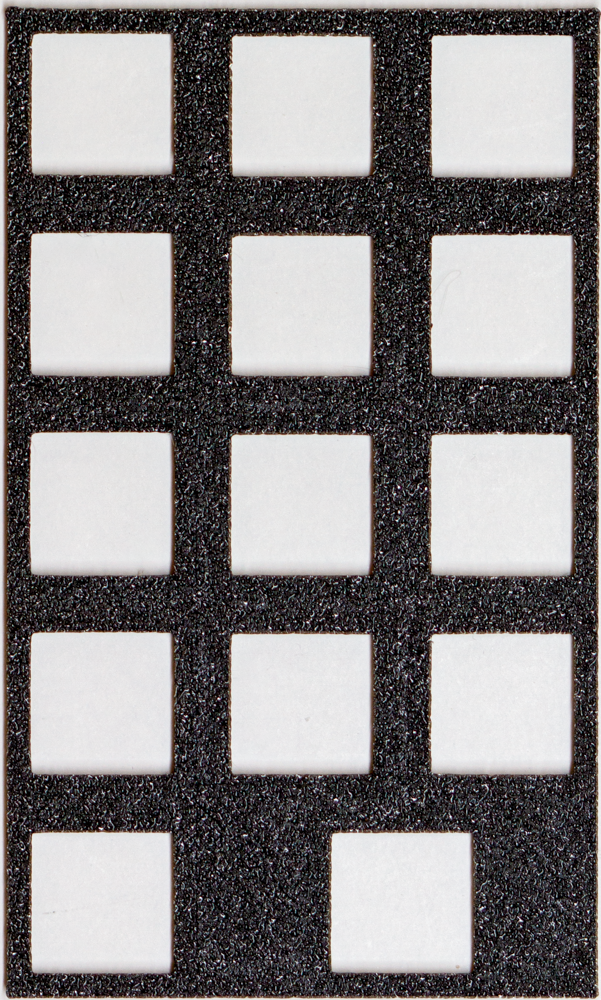
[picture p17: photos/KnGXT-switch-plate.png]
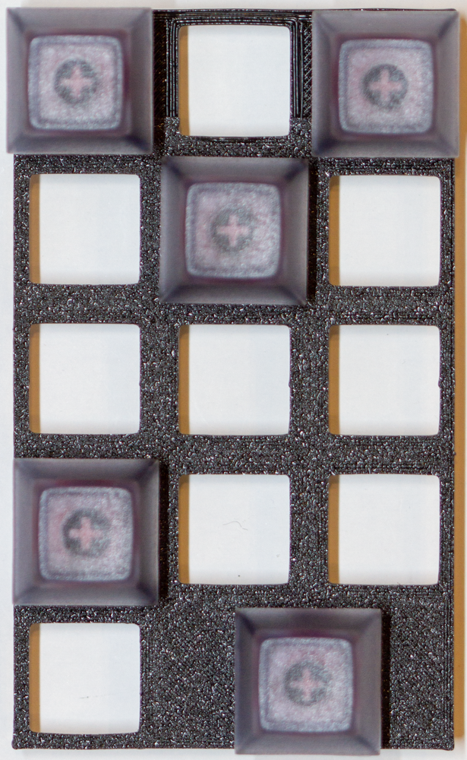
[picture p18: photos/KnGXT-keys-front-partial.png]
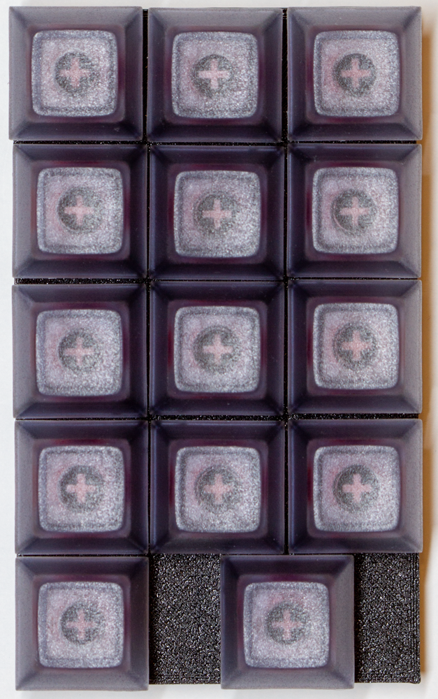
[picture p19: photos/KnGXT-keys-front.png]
| |  |  |
| :-: | :-: | :--: |
| _Empty switch plate_ | _Partially populated_ | _Fully populated_ |

**The orientation of the keyswitches is important.** Make sure that the pins are at the top, not rotated.

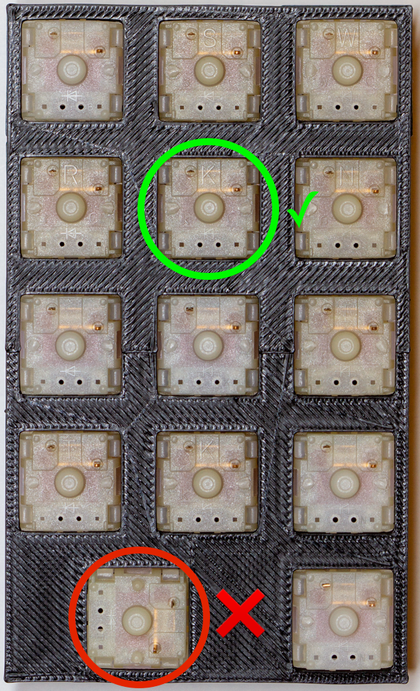
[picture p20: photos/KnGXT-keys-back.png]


Once the switches are in the plate, **carefully** insert the switch pins into
the hotswap sockets, then press firmly to fully seat everything. Finish by
setting the board into the bottom of its case, LEDs up, rotary encoders on the
  left.

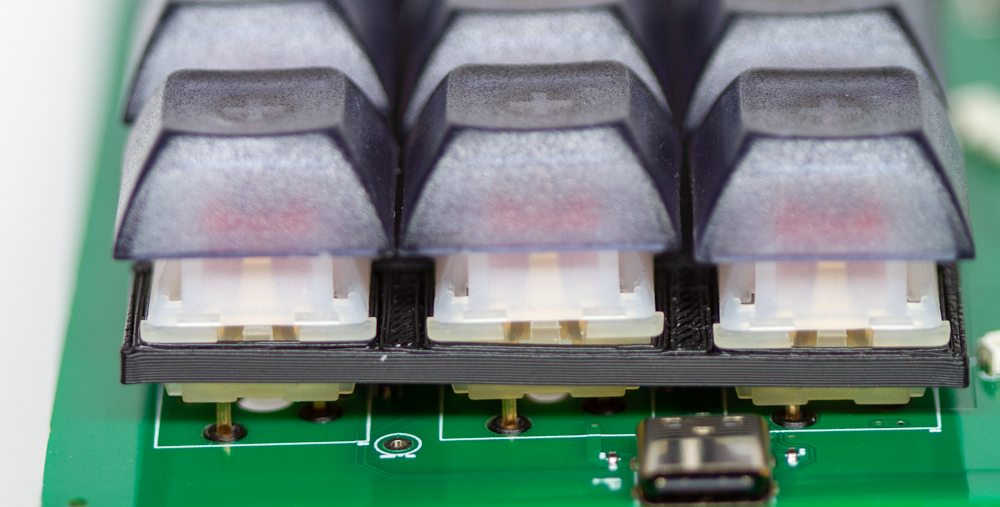
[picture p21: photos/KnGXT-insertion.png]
|  |
| :-: |
| _Make very sure the pins line up with the hotswap holes..._ |

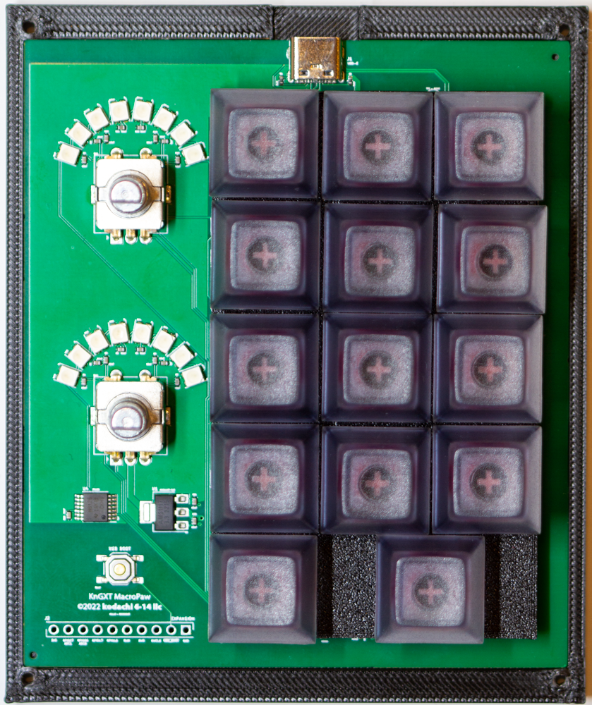
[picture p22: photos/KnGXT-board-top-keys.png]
|  |
| :-: |
| _...before fully seating the keys into the board and laying in on the case bottom._ |

## Full Hardware Test

Once you have rotary encoders and switches installed, you can do the full
hardware test. Plug the MacroPaw back in; it should reboot to hardware test
mode again.

Once all the LEDs are dim white:

- Turning a rotary encoder counterclockwise should cause its ring of LEDs to
  turn red.

- Turning a rotary encoder clockwise should cause its ring of LEDs to turn
  green.

- Pressing a rotary encoder should cause its ring of LEDs to turn blue.
  Pressing it again should turn its LEDs off.

- Pressing a key should change its LED to red. Repeated presses should turn it
  green, then blue, then off.

- When you've cycled all the LEDs have gone through all their colors, you
  should see all the LEDs turn green again. Unplug the MacroPaw and plug it
  back in to exit hardware test.

## Install into Case

Installing the KnGXT into its case is fairly straightforward.

- Make sure the rotary encoders have neither their knobs nor locking nuts on
  their shafts.

- With the MacroPaw already in the bottom half of the case (LEDs up, rotary
  encoders on the left), lay the top half of the case over the MacroPaw (it
  will go neatly over the key switches).

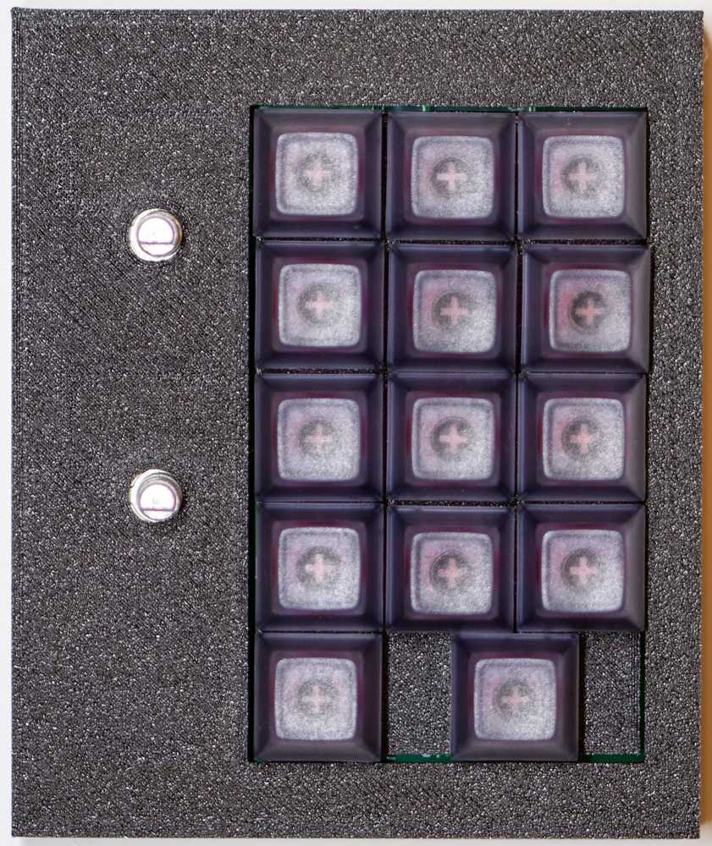
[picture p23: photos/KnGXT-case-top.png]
  

- Screw the rotary encoder locking nuts on, just finger-tight: overdoing it
  could bend the case, or cause the case to always be pressing the BOOT
  button.

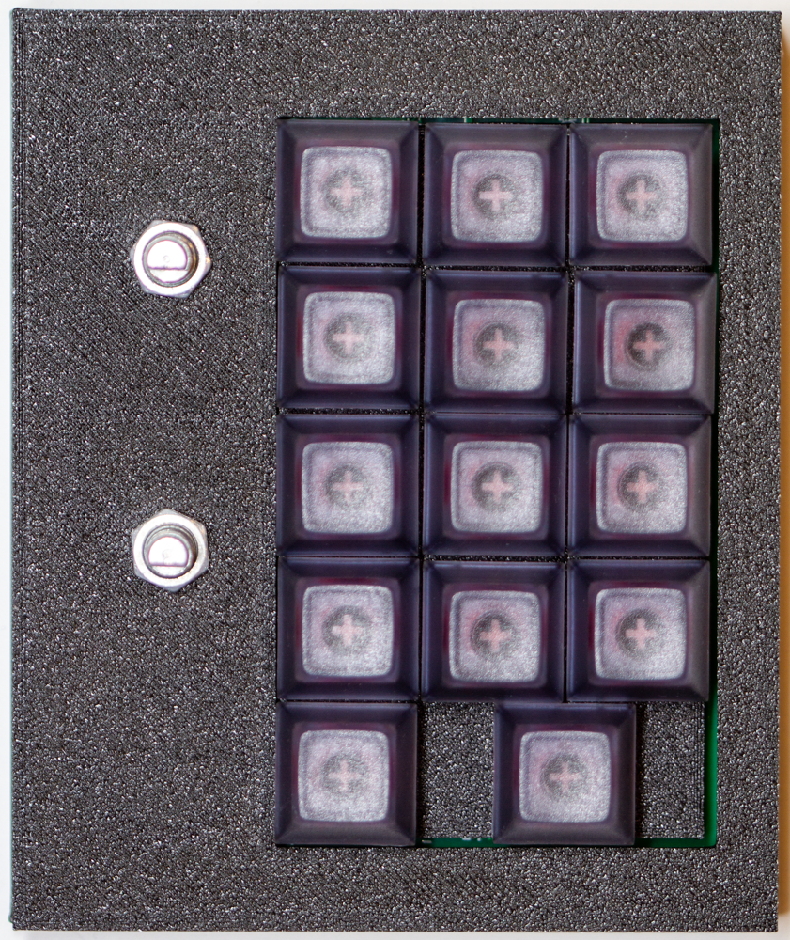
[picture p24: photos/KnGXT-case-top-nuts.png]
  

- Put the rotary encoder knobs on.

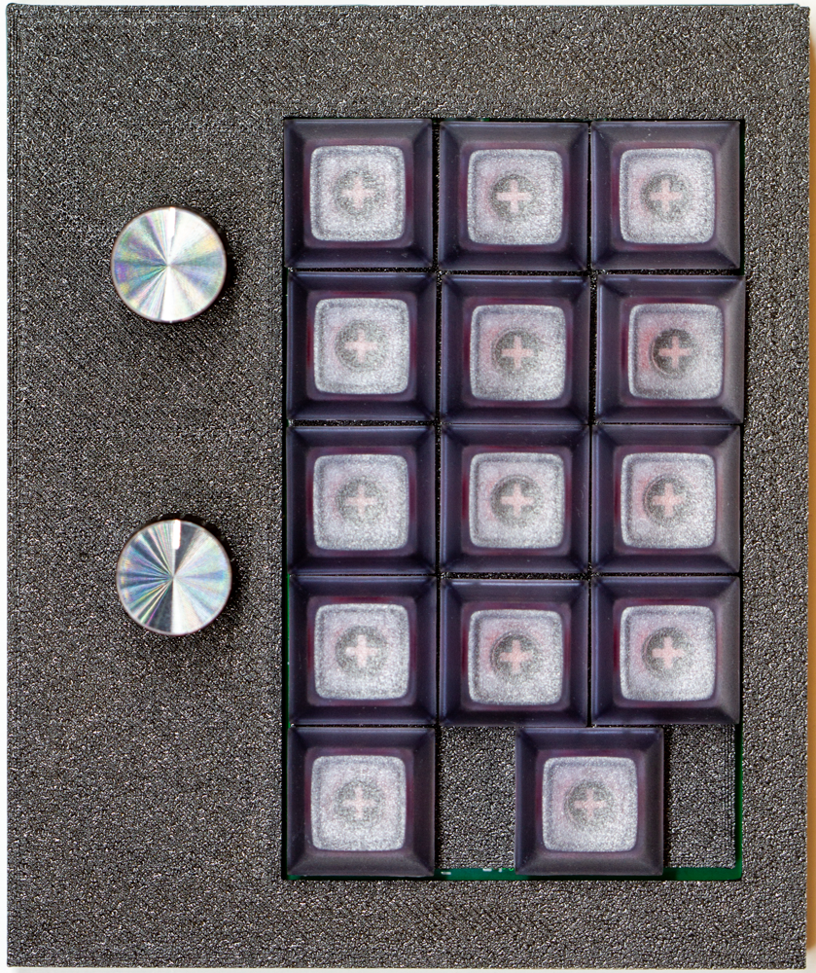
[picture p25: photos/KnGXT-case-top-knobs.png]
  

- Screw the board halves together with four 1/2-inch #4 screws.

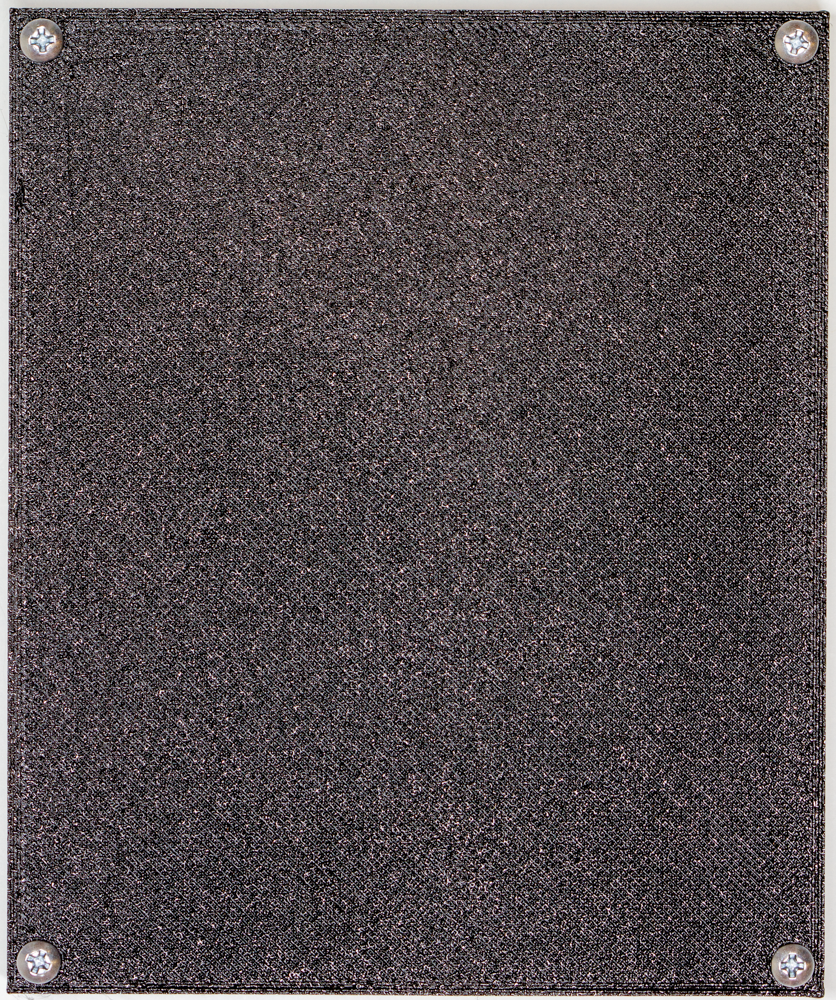
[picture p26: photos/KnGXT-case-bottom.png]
  

- Plug the board back in!

## Using Your MacroPaw

After leaving hardware test mode, your MacroPaw should be a real keyboard. It
should flash all its lights yellow when first booting, then start a blue
"breathing" animation with the LEDs under the keys repeatedly cycling across
brightnesses. Check out the [User Guide] for more on using your MacroPaw.

[BUILDING.md]: BUILDING.md
[User Guide]: USERGUIDE.md

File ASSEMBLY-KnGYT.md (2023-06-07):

# MacroPaw KnGYT Assembly Guide

The MacroPaw KnGYT was produced as a fully-assembled two-sided PCB board:
everything except keyswitches was assembled at the factory. To assemble a
KnGYT you need to put the PCB into its case and install keyswitches.

- Install switches
- Factory reset (optional with a new board)
- Install firmware
- Hardware test
- Install into case

## Install Switches

Since the KnGYT has its hotswap sockets in place from the factory, there's no
reason not to install the switches before anything else, to be able to do a
proper hardware test. The easiest way to install the switches into a KnGYT is
to set the switch plate on top of the PCB (make sure the notch in the plate is
at the upper left of the board, when viewing the PCB from the top with the USB
port on the left), then **carefully** insert switches one at a time through
the plate into the hotswap sockets.

Install all ten switches before proceeding.

## Factory Reset

To completely reset a KnGYT to new-out-of-the-factory condition, you need to
wipe its onboard flash memory. **WARNING: this will, of course, erase any
customization you've done.**

1. Grab David Welch's `flash_nuke.uf2` from
   https://github.com/dwelch67/raspberrypi-pico. This is a minimal RP2040
   program to completely wipe the attached flash.

   ```bash
   curl -o /tmp/flash_nuke.uf2 https://github.com/dwelch67/raspberrypi-pico/raw/main/flash_nuke.uf2
   ```

2. If your KnGYT doesn't already show up as the `RPI_RP2` volume when you plug
   it in, hold down the USB_BOOT button on the MacroPaw KnGYT board and plug
   it into your computer with a USB-C cable. (If it's already plugged in,
   press and release the RESET button while still holding USB_BOOT, then
   release USB_BOOT.) The KnGYT should appear as a USB Mass Storage device
   named `RPI_RP2` on your computer.

3. Copy `flash_nuke.uf2` to the `RPI_RP2` volume. On a Mac, this is most simply done with

   ```bash
   cp /tmp/macropaw-KnGYT.uf2 /Volumes/RPI_RP2
   ```

4. The `RPI_RP2` volume will vanish while `flash_nuke` runs, then return once it's done.

## Install Firmware

1. Grab the most recent MacroPaw KnGYT firmware from www.kodachi.com:

   ```bash
   curl -o /tmp/macropaw-KnGYT.uf2 https://www.kodachi.com/firmware/macropaw-KnGYT.uf2
   ```

   (Alternately, you can build your own firmware: follow the docs in [BUILDING.md].)

2. If your KnGYT doesn't already show up as the `RPI_RP2` volume when you plug
   it in, hold down the USB_BOOT button on the MacroPaw KnGYT board and plug
   it into your computer with a USB-C cable. (If it's already plugged in,
   press and release the RESET button while still holding USB_BOOT, then
   release USB_BOOT.) The KnGYT should appear as a USB Mass Storage device
   named `RPI_RP2` on your computer.

3. Copy the firmware to the `RPI_RP2` volume. On a Mac, this is most simply done with

   ```bash
   cp /tmp/macropaw-KnGYT.uf2 /Volumes/RPI_RP2
   ```

   **This step can take awhile**; 30-60 seconds is not unusual.

4. Wait for the KnGYT to reboot into hardware test mode.

## Hardware Test

The first time a MacroPaw is booted after new firmware is installed, it will
launch in _hardware test mode_. This mode doesn't function as a keyboard:
instead, it lets you verify that the LEDs, keyswitches, and rotary encoders on
the board work.

When booting in hardware test mode, all the lights will flash yellow at
startup. The LEDs should then cycle through red, green, and blue, then end up
all at a dim white.

Once all the LEDs are dim white, pressing a key should change its LED to red.
Repeated presses should turn it green, then blue, then off. When you've cycled
all the LEDs have gone through all their colors, you should see all the LEDs
turn green again. Press the RESET button on the MacroPaw to exit hardware
test.

## Install into Case

Installing the KnGYT into its case is fairly straightforward.

- Lay the MacroPaw into the bottom half of the case, switches up, USB port to
  the left.

- Lay the top half of the case over the MacroPaw and switch plate.

- Slide the end caps onto the ends of the case. Make sure you use the end cap
  with a port on the USB-port side of the MacroPaw. (Obviously, you'll need to
  unplug the MacroPaw to do this.)

- Plug the board back in!

## Using Your MacroPaw

After leaving hardware test mode, your MacroPaw should be a real keyboard. It
should flash all its lights yellow when first booting, then start a blue
"breathing" animation with the LEDs under the keys repeatedly cycling across
brightnesses. Check out the [User Guide] for more on using your MacroPaw.

[BUILDING.md]: BUILDING.md
[User Guide]: USERGUIDE.md

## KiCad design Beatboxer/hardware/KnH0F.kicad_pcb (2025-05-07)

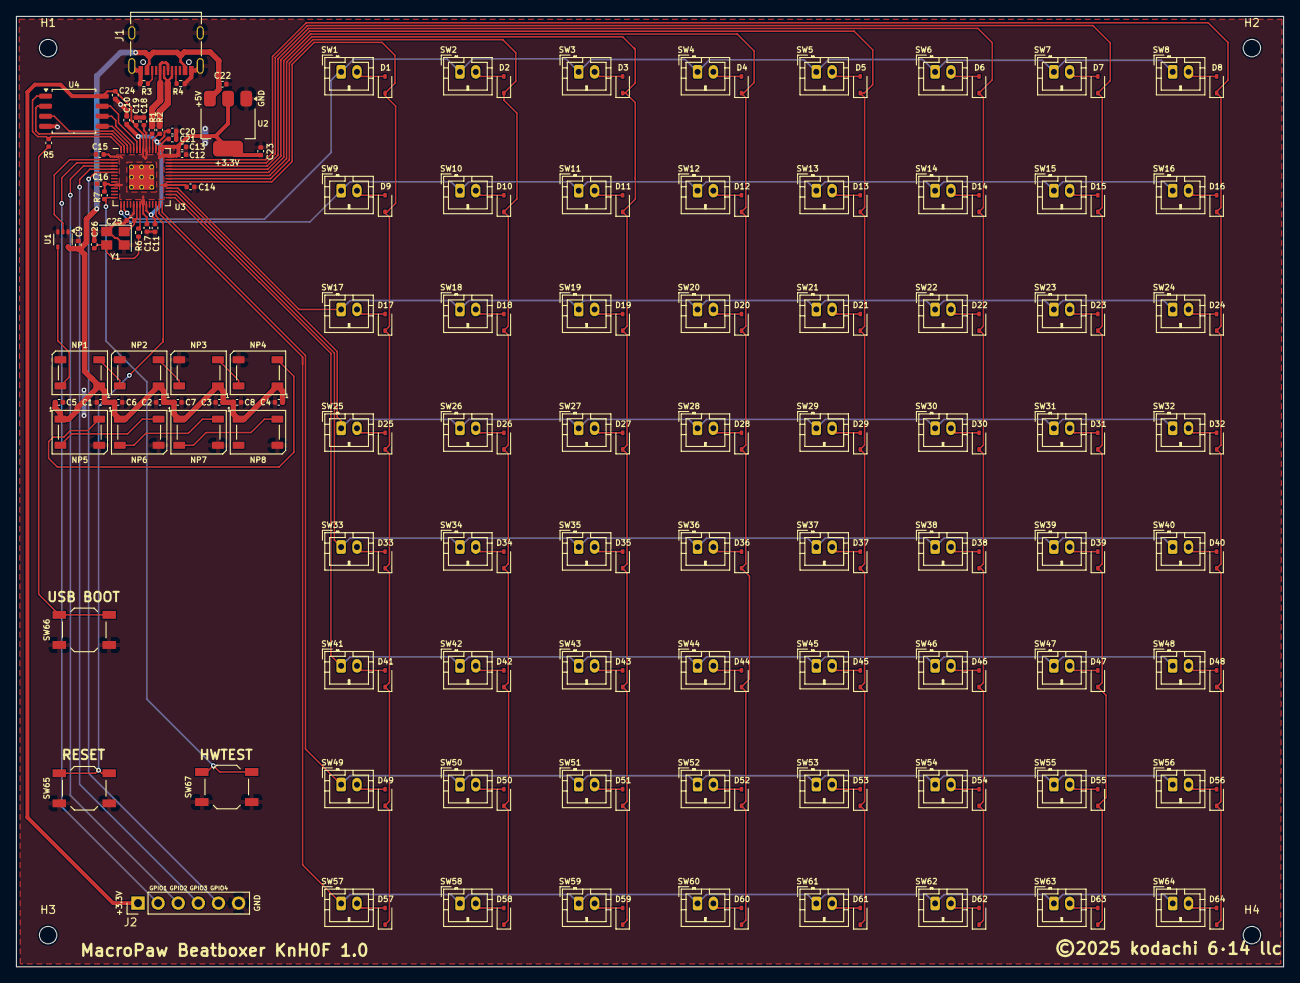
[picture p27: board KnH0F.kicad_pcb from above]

Board: 2 copper layers, 160.0 x 120.0 mm, 183 parts (0 on the bottom side), 115 nets.

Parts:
C1, C2, C3, C4, C5, C6, C7, C8, C9, C22, C23, C24: 10uF; C_0402_1005Metric
C10, C11, C12, C13, C14, C15, C16, C17, C18, C19: 100nF; C_0402_1005Metric
C20, C21: 1uF; C_0402_1005Metric
C25, C26: 30pF; C_0402_1005Metric
D1, D2, D3, D4, D5, D6, D7, D8, D9, D10, D11, D12, D13, D14, D15, D16, D17, D18, D19, D20, D21, D22, D23, D24, D25, D26, D27, D28, D29, D30, D31, D32, D33, D34, D35, D36, D37, D38, D39, D40, D41, D42, D43, D44, D45, D46, D47, D48, D49, D50, D51, D52, D53, D54, D55, D56, D57, D58, D59, D60, D61, D62, D63, D64: 1N4148; D_SOD-323
H1, H2, H3, H4: MountingHole; MountingHole_2.2mm_M2
J1: USB_C_Receptacle_USB2.0_16P; USB_C_Receptacle_Palconn_UTC16-G
J2: Conn_01x06_Pin; PinHeader_1x06_P2.54mm_Vertical
NP1, NP2, NP3, NP4, NP5, NP6, NP7, NP8: WS2812B; LED_WS2812B_PLCC4_5.0x5.0mm_P3.2mm
R1, R2: 27; C_0402_1005Metric
R3, R4: 5.1k; R_0402_1005Metric
R5, R7: 1k; C_0402_1005Metric
R6: 1k; R_0402_1005Metric
SW1, SW2, SW3, SW4, SW5, SW6, SW7, SW8, SW9, SW10, SW11, SW12, SW13, SW14, SW15, SW16, SW17, SW18, SW19, SW20, SW21, SW22, SW23, SW24, SW25, SW26, SW27, SW28, SW29, SW30, SW31, SW32, SW33, SW34, SW35, SW36, SW37, SW38, SW39, SW40, SW41, SW42, SW43, SW44, SW45, SW46, SW47, SW48, SW49, SW50, SW51, SW52, SW53, SW54, SW55, SW56, SW57, SW58, SW59, SW60, SW61, SW62, SW63, SW64: SW_Push_45deg; JST_PH_B2B-PH-K_1x02_P2.00mm_Vertical
SW65, SW66, SW67: SW_Push; SW_SPST_TL3342
U1: 74AHC1G125; SOT-353_SC-70-5
U2: AMS1117-3.3; SOT-223-3_TabPin2
U3: RP2040; RP2040-QFN-56
U4: W25Q128JVS; SOIC-8_5.3x5.3mm_P1.27mm
Y1: 12MHz; Crystal_SMD_3225-4Pin_3.2x2.5mm

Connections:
+1V1: C10.1, C11.1, C20.1, U3.23 (DVDD), U3.45 (VREG_VOUT), U3.50 (DVDD)
+3V3: C12.1, C13.1, C14.1, C15.1, C16.1, C17.1, C18.1, C19.1, C21.1, C23.1, C24.1, J2.1, R7.1, U2.2 (VO), U3.1 (IOVDD), U3.10 (IOVDD), U3.22 (IOVDD), U3.33 (IOVDD), U3.42 (IOVDD), U3.43 (ADC_AVDD), U3.44 (VREG_IN), U3.48 (USB_VDD), U3.49 (IOVDD), U4.8 (VCC)
+5V: C1.1, C2.1, C3.1, C4.1, C5.1, C6.1, C7.1, C8.1, C9.1, C22.1, J1.A4 (VBUS), J1.A9 (VBUS), J1.B4 (VBUS), J1.B9 (VBUS), NP1.1 (VDD), NP2.1 (VDD), NP3.1 (VDD), NP4.1 (VDD), NP5.1 (VDD), NP6.1 (VDD), NP7.1 (VDD), NP8.1 (VDD), U1.5 (VCC), U2.3 (VI)
/GPIO1: J2.2, U3.3 (GPIO1)
/GPIO2: J2.3, U3.4 (GPIO2)
/GPIO3: J2.4, U3.5 (GPIO3)
/GPIO4: J2.5, U3.6 (GPIO4)
/HWTEST: R7.2, SW67.1, U3.14 (GPIO11)
/NEO3V3: U1.2, U3.2 (GPIO0)
/NEOPXL: NP1.4 (DIN), U1.4
/QSPI_SCLK: U3.52 (QSPI_SCLK), U4.6 (CLK)
/QSPI_SD0: U3.53 (QSPI_SD0), U4.5 (DI/IO_{0})
/QSPI_SD1: U3.55 (QSPI_SD1), U4.2 (DO/IO_{1})
/QSPI_SD2: U3.54 (QSPI_SD2), U4.3 (~WP/IO_{2})
/QSPI_SD3: U3.51 (QSPI_SD3), U4.7 (~HOLD/~RESET/IO_{3})
/QSPI_SS: R5.1, U3.56 (QSPI_SS), U4.1 (~CS)
/RUN: SW65.2, U3.26 (RUN)
/USB_CC1: J1.A5 (CC1), R4.2
/USB_CC2: J1.B5 (CC2), R3.2
/USB_D+: J1.A6 (D+), J1.B6 (D+), R1.1
/USB_D-: J1.A7 (D-), J1.B7 (D-), R2.1
/XIN: C25.1, U3.20 (XIN), Y1.1
/XOUT: R6.1, U3.21 (XOUT)
/~USB_BOOT: R5.2, SW66.2
COL0: D1.1 (K), D9.1 (K), D17.1 (K), D25.1 (K), D33.1 (K), D41.1 (K), D49.1 (K), D57.1 (K), U3.34 (GPIO22)
COL1: D2.1 (K), D10.1 (K), D18.1 (K), D26.1 (K), D34.1 (K), D42.1 (K), D50.1 (K), D58.1 (K), U3.35 (GPIO23)
COL2: D3.1 (K), D11.1 (K), D19.1 (K), D27.1 (K), D35.1 (K), D43.1 (K), D51.1 (K), D59.1 (K), U3.36 (GPIO24)
COL3: D4.1 (K), D12.1 (K), D20.1 (K), D28.1 (K), D36.1 (K), D44.1 (K), D52.1 (K), D60.1 (K), U3.37 (GPIO25)
COL4: D5.1 (K), D13.1 (K), D21.1 (K), D29.1 (K), D37.1 (K), D45.1 (K), D53.1 (K), D61.1 (K), U3.38 (GPIO26_ADC0)
COL5: D6.1 (K), D14.1 (K), D22.1 (K), D30.1 (K), D38.1 (K), D46.1 (K), D54.1 (K), D62.1 (K), U3.39 (GPIO27_ADC1)
COL6: D7.1 (K), D15.1 (K), D23.1 (K), D31.1 (K), D39.1 (K), D47.1 (K), D55.1 (K), D63.1 (K), U3.40 (GPIO28_ADC2)
COL7: D8.1 (K), D16.1 (K), D24.1 (K), D32.1 (K), D40.1 (K), D48.1 (K), D56.1 (K), D64.1 (K), U3.41 (GPIO29_ADC3)
GND: C1.2, C2.2, C3.2, C4.2, C5.2, C6.2, C7.2, C8.2, C9.2, C10.2, C11.2, C12.2, C13.2, C14.2, C15.2, C16.2, C17.2, C18.2, C19.2, C20.2, C21.2, C22.2, C23.2, C24.2, C25.2, C26.2, J1.A1 (GND), J1.A12 (GND), J1.B1 (GND), J1.B12 (GND), J1.S1 (SHIELD), J2.6, NP1.3 (VSS), NP2.3 (VSS), NP3.3 (VSS), NP4.3 (VSS), NP5.3 (VSS), NP6.3 (VSS), NP7.3 (VSS), NP8.3 (VSS), R3.1, R4.1, SW65.1, SW66.1, SW67.2, U1.1, U1.3 (GND), U2.1 (GND), U3.19 (TESTEN), U3.57 (GND), U4.4 (GND), Y1.2, Y1.4
unnamed: C26.1, R6.2, Y1.3
unnamed: D1.2 (A), SW1.2
unnamed: D2.2 (A), SW2.2
unnamed: D3.2 (A), SW3.2
unnamed: D4.2 (A), SW4.2
unnamed: D5.2 (A), SW5.2
unnamed: D6.2 (A), SW6.2
unnamed: D7.2 (A), SW7.2
unnamed: D8.2 (A), SW8.2
unnamed: D9.2 (A), SW9.2
unnamed: D10.2 (A), SW10.2
unnamed: D11.2 (A), SW11.2
unnamed: D12.2 (A), SW12.2
unnamed: D13.2 (A), SW13.2
unnamed: D14.2 (A), SW14.2
unnamed: D15.2 (A), SW15.2
unnamed: D16.2 (A), SW16.2
unnamed: D17.2 (A), SW17.2
unnamed: D18.2 (A), SW18.2
unnamed: D19.2 (A), SW19.2
unnamed: D20.2 (A), SW20.2
unnamed: D21.2 (A), SW21.2
unnamed: D22.2 (A), SW22.2
unnamed: D23.2 (A), SW23.2
unnamed: D24.2 (A), SW24.2
unnamed: D25.2 (A), SW25.2
unnamed: D26.2 (A), SW26.2
unnamed: D27.2 (A), SW27.2
unnamed: D28.2 (A), SW28.2
unnamed: D29.2 (A), SW29.2
unnamed: D30.2 (A), SW30.2
unnamed: D31.2 (A), SW31.2
unnamed: D32.2 (A), SW32.2
unnamed: D33.2 (A), SW33.2
unnamed: D34.2 (A), SW34.2
unnamed: D35.2 (A), SW35.2
unnamed: D36.2 (A), SW36.2
unnamed: D37.2 (A), SW37.2
unnamed: D38.2 (A), SW38.2
unnamed: D39.2 (A), SW39.2
unnamed: D40.2 (A), SW40.2
unnamed: D41.2 (A), SW41.2
unnamed: D42.2 (A), SW42.2
unnamed: D43.2 (A), SW43.2
unnamed: D44.2 (A), SW44.2
unnamed: D45.2 (A), SW45.2
unnamed: D46.2 (A), SW46.2
unnamed: D47.2 (A), SW47.2
unnamed: D48.2 (A), SW48.2
unnamed: D49.2 (A), SW49.2
unnamed: D50.2 (A), SW50.2
unnamed: D51.2 (A), SW51.2
unnamed: D52.2 (A), SW52.2
unnamed: D53.2 (A), SW53.2
unnamed: D54.2 (A), SW54.2
unnamed: D55.2 (A), SW55.2
unnamed: D56.2 (A), SW56.2
unnamed: D57.2 (A), SW57.2
unnamed: D58.2 (A), SW58.2
unnamed: D59.2 (A), SW59.2
unnamed: D60.2 (A), SW60.2
unnamed: D61.2 (A), SW61.2
unnamed: D62.2 (A), SW62.2
unnamed: D63.2 (A), SW63.2
unnamed: D64.2 (A), SW64.2
unnamed: NP1.2 (DOUT), NP2.4 (DIN)
unnamed: NP2.2 (DOUT), NP3.4 (DIN)
unnamed: NP3.2 (DOUT), NP4.4 (DIN)
unnamed: NP4.2 (DOUT), NP5.4 (DIN)
unnamed: NP5.2 (DOUT), NP6.4 (DIN)
unnamed: NP6.2 (DOUT), NP7.4 (DIN)
unnamed: NP7.2 (DOUT), NP8.4 (DIN)
unnamed: R2.2, U3.46 (USB_DM)
unnamed: R1.2, U3.47 (USB_DP)
ROW0: SW1.1, SW2.1, SW3.1, SW4.1, SW5.1, SW6.1, SW7.1, SW8.1, U3.16 (GPIO13)
ROW1: SW9.1, SW10.1, SW11.1, SW12.1, SW13.1, SW14.1, SW15.1, SW16.1, U3.15 (GPIO12)
ROW2: SW17.1, SW18.1, SW19.1, SW20.1, SW21.1, SW22.1, SW23.1, SW24.1, U3.32 (GPIO21)
ROW3: SW25.1, SW26.1, SW27.1, SW28.1, SW29.1, SW30.1, SW31.1, SW32.1, U3.31 (GPIO20)
ROW4: SW33.1, SW34.1, SW35.1, SW36.1, SW37.1, SW38.1, SW39.1, SW40.1, U3.30 (GPIO19)
ROW5: SW41.1, SW42.1, SW43.1, SW44.1, SW45.1, SW46.1, SW47.1, SW48.1, U3.29 (GPIO18)
ROW6: SW49.1, SW50.1, SW51.1, SW52.1, SW53.1, SW54.1, SW55.1, SW56.1, U3.28 (GPIO17)
ROW7: SW57.1, SW58.1, SW59.1, SW60.1, SW61.1, SW62.1, SW63.1, SW64.1, U3.27 (GPIO16)

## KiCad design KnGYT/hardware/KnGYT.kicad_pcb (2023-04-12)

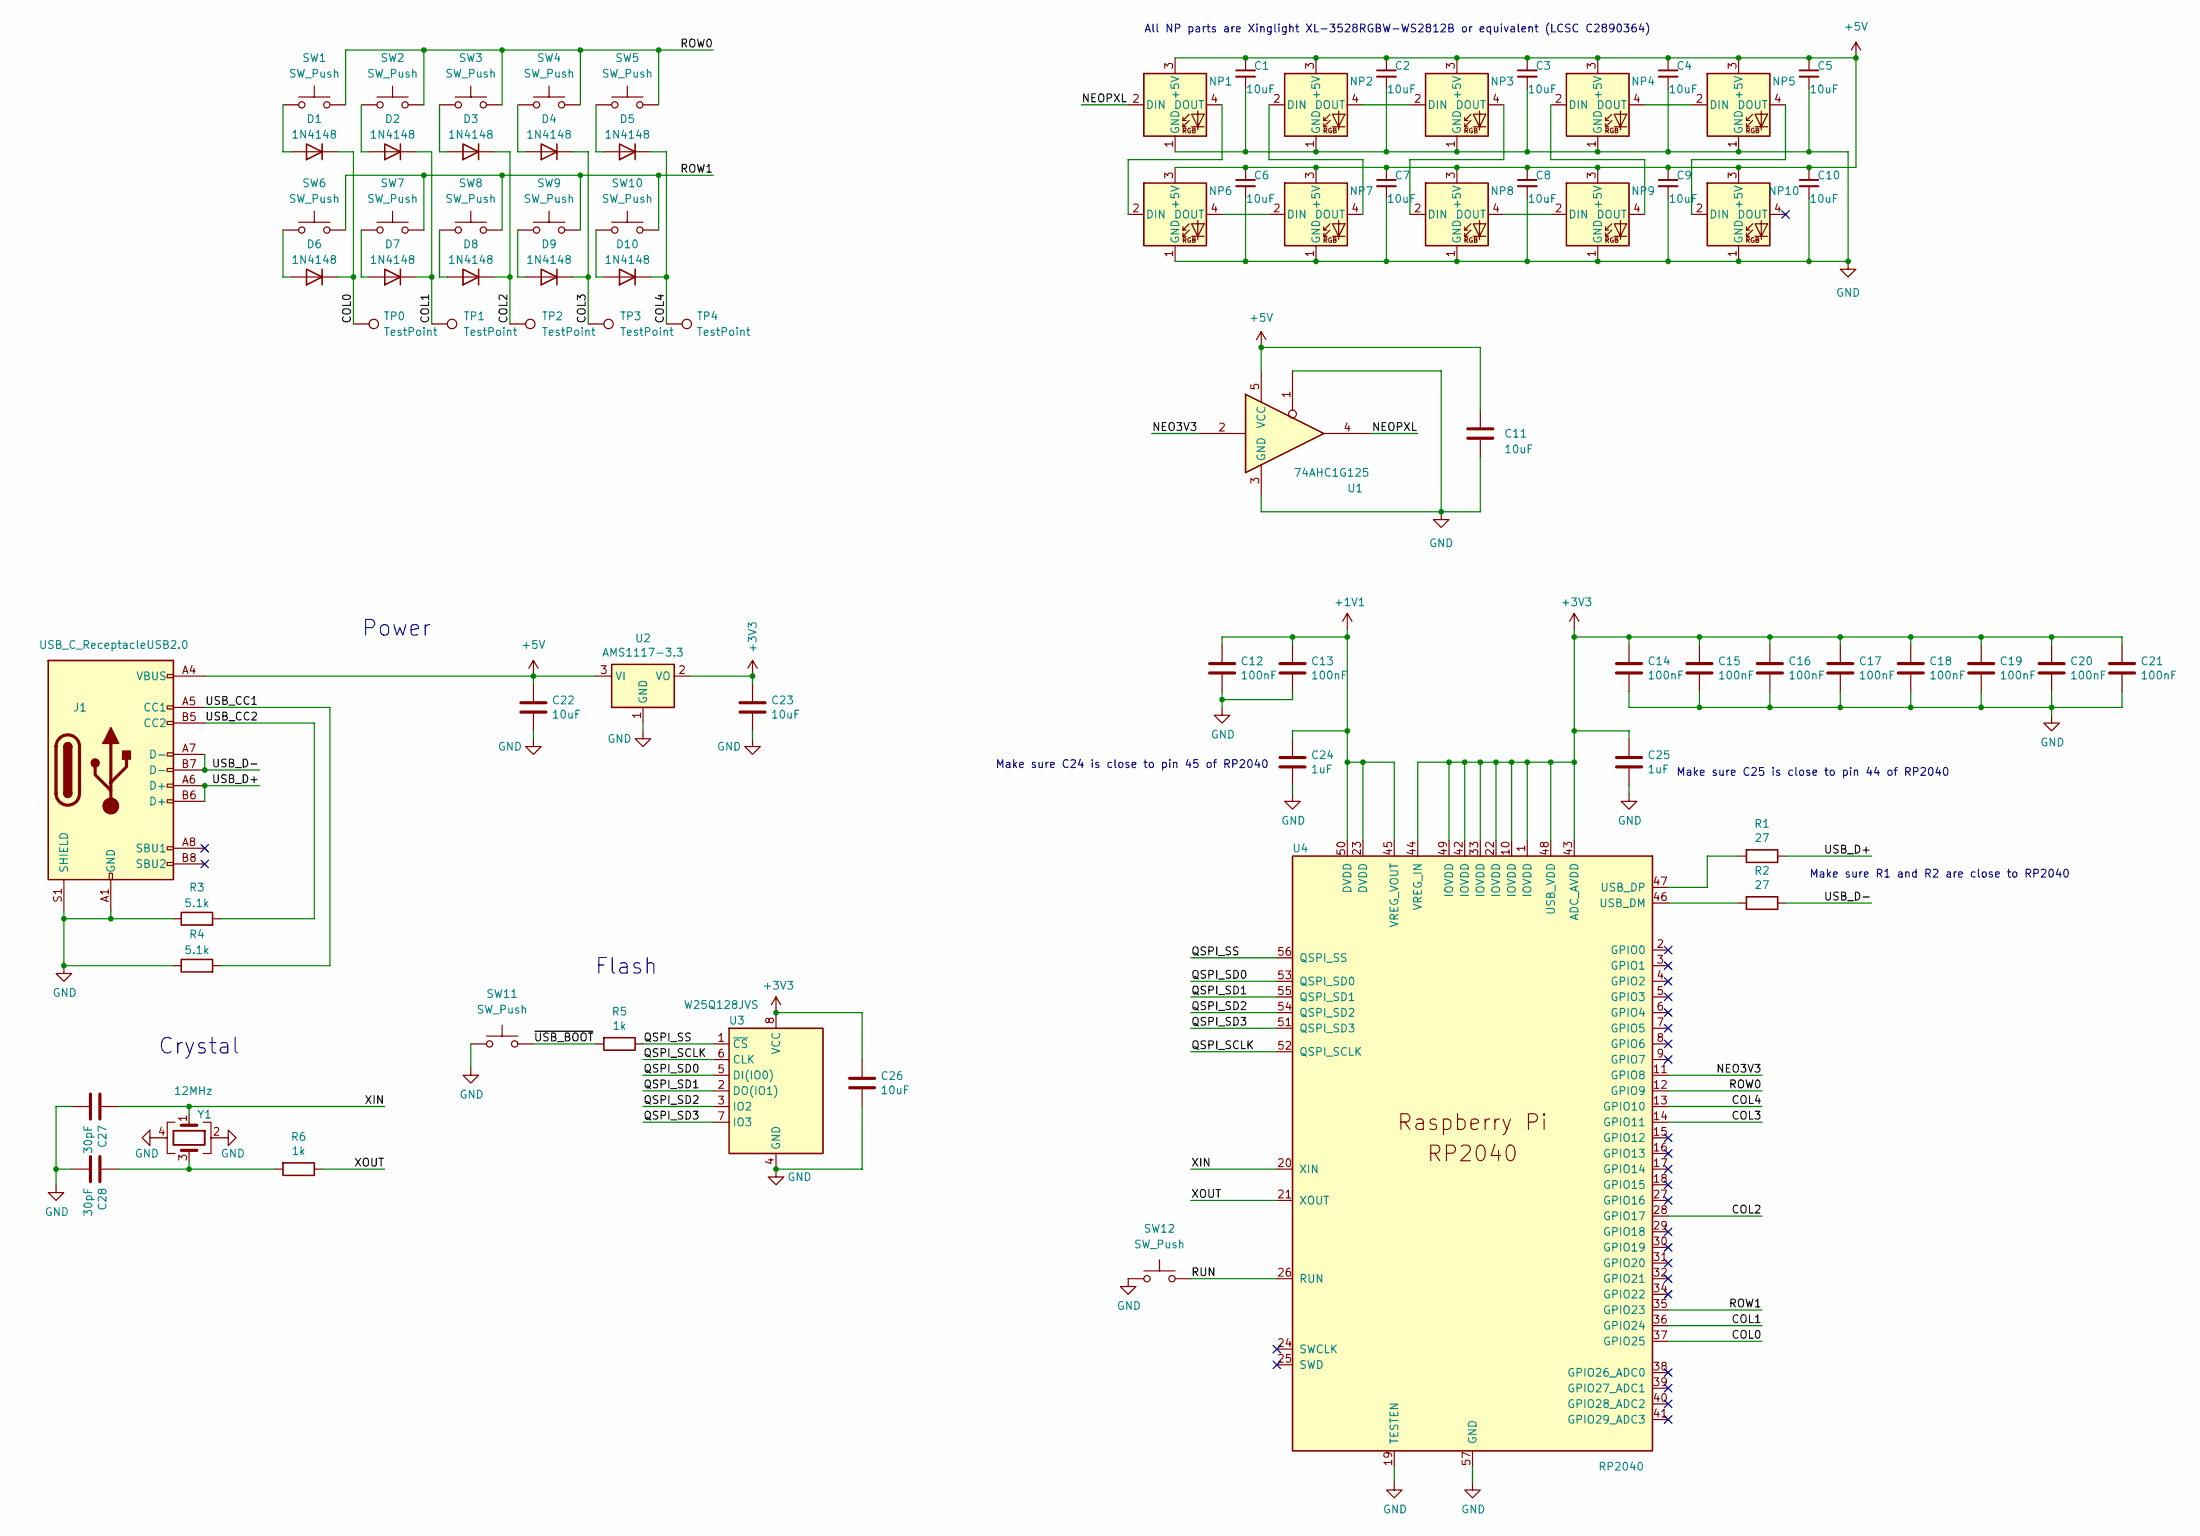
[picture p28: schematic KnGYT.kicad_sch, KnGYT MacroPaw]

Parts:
C1, C2, C3, C4, C5, C6, C7, C8, C9, C10, C11, C22, C23, C26: 10uF; C_0402_1005Metric; LCSC C15525
C12, C13, C14, C15, C16, C17, C18, C19, C20, C21: 100nF; C_0402_1005Metric; LCSC C1525
C24, C25: 1uF; C_0402_1005Metric; LCSC C52923
C27, C28: 30pF; C_0402_1005Metric; LCSC C1570
D1, D2, D3, D4, D5, D6, D7, D8, D9, D10: 1N4148; D_SOD-323F; LCSC C2128
J1: USB_C_ReceptacleUSB2.0; USB_C_Receptacle_Palconn_UTC16-G; LCSC C165948
NP1, NP2, NP3, NP4, NP5, NP6, NP7, NP8, NP9, NP10: WS2812B; LED XL-3528RGBW-WS2812B (3.5x2.8, C2890364); LCSC C2890364
R1, R2: 27; C_0402_1005Metric; LCSC C25100
R3, R4: 5.1k; R_0402_1005Metric; LCSC C25905
R5: 1k; C_0402_1005Metric; LCSC C11702
R6: 1k; R_0402_1005Metric; LCSC C11702
SW1, SW2, SW3, SW4, SW5, SW6, SW7, SW8, SW9, SW10: SW_Push; Flipped_Hotswap_Kailh_MX_1.00u (C5184526); LCSC C5184526
SW11, SW12: SW_Push; SW_SPST_TL3342; LCSC C318884
TP0, TP1, TP2, TP3, TP4: TestPoint; TestPoint_Pad_1.5x1.5mm
U1: 74AHC1G125; SOT-353_SC-70-5; LCSC C151417
U2: AMS1117-3.3; SOT-223-3_TabPin2; LCSC C6186
U3: W25Q128JVS; SOIC-8_5.23x5.23mm_P1.27mm; LCSC C97521
U4: RP2040; RP2040-QFN-56; LCSC C2040
Y1: 12MHz; Crystal_SMD_3225-4Pin_3.2x2.5mm; LCSC C9002

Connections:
+1V1: C12.1, C13.1, C24.1, U4.23 (DVDD), U4.45 (VREG_VOUT), U4.50 (DVDD)
+3V3: C14.1, C15.1, C16.1, C17.1, C18.1, C19.1, C20.1, C21.1, C23.1, C25.1, C26.1, U2.2 (VO), U3.8 (VCC), U4.1 (IOVDD), U4.10 (IOVDD), U4.22 (IOVDD), U4.33 (IOVDD), U4.42 (IOVDD), U4.43 (ADC_AVDD), U4.44 (VREG_IN), U4.48 (USB_VDD), U4.49 (IOVDD)
+5V: C1.1, C2.1, C3.1, C4.1, C5.1, C6.1, C7.1, C8.1, C9.1, C10.1, C11.1, C22.1, J1.A4 (VBUS), J1.A9 (VBUS), J1.B4 (VBUS), J1.B9 (VBUS), NP1.3 (+5V), NP2.3 (+5V), NP3.3 (+5V), NP4.3 (+5V), NP5.3 (+5V), NP6.3 (+5V), NP7.3 (+5V), NP8.3 (+5V), NP9.3 (+5V), NP10.3 (+5V), U1.5 (VCC), U2.3 (VI)
/COL0: D1.1 (K), D6.1 (K), TP0.1, U4.37 (GPIO25)
/COL1: D2.1 (K), D7.1 (K), TP1.1, U4.36 (GPIO24)
/COL2: D3.1 (K), D8.1 (K), TP2.1, U4.28 (GPIO17)
/COL3: D4.1 (K), D9.1 (K), TP3.1, U4.14 (GPIO11)
/COL4: D5.1 (K), D10.1 (K), TP4.1, U4.13 (GPIO10)
/NEO3V3: U1.2, U4.11 (GPIO8)
/NEOPXL: NP1.2 (DIN), U1.4
/QSPI_SCLK: U3.6 (CLK), U4.52 (QSPI_SCLK)
/QSPI_SD0: U3.5 (DI(IO0)), U4.53 (QSPI_SD0)
/QSPI_SD1: U3.2 (DO(IO1)), U4.55 (QSPI_SD1)
/QSPI_SD2: U3.3 (IO2), U4.54 (QSPI_SD2)
/QSPI_SD3: U3.7 (IO3), U4.51 (QSPI_SD3)
/QSPI_SS: R5.1, U3.1 (~CS), U4.56 (QSPI_SS)
/ROW0: SW1.2, SW2.2, SW3.2, SW4.2, SW5.2, U4.12 (GPIO9)
/ROW1: SW6.2, SW7.2, SW8.2, SW9.2, SW10.2, U4.35 (GPIO23)
/RUN: SW12.2, U4.26 (RUN)
/USB_CC1: J1.A5 (CC1), R4.2
/USB_CC2: J1.B5 (CC2), R3.2
/USB_D+: J1.A6 (D+), J1.B6 (D+), R1.1
/USB_D-: J1.A7 (D-), J1.B7 (D-), R2.1
/XIN: C27.1, U4.20 (XIN), Y1.1
/XOUT: R6.1, U4.21 (XOUT)
/~USB_BOOT: R5.2, SW11.2
GND: C1.2, C2.2, C3.2, C4.2, C5.2, C6.2, C7.2, C8.2, C9.2, C10.2, C11.2, C12.2, C13.2, C14.2, C15.2, C16.2, C17.2, C18.2, C19.2, C20.2, C21.2, C22.2, C23.2, C24.2, C25.2, C26.2, C27.2, C28.2, J1.A1 (GND), J1.A12 (GND), J1.B1 (GND), J1.B12 (GND), J1.S1 (SHIELD), NP1.1 (GND), NP2.1 (GND), NP3.1 (GND), NP4.1 (GND), NP5.1 (GND), NP6.1 (GND), NP7.1 (GND), NP8.1 (GND), NP9.1 (GND), NP10.1 (GND), R3.1, R4.1, SW11.1, SW12.1, U1.1, U1.3 (GND), U2.1 (GND), U3.4 (GND), U4.19 (TESTEN), U4.57 (GND), Y1.2, Y1.4
unnamed: C28.1, R6.2, Y1.3
unnamed: D1.2 (A), SW1.1
unnamed: D2.2 (A), SW2.1
unnamed: D3.2 (A), SW3.1
unnamed: D4.2 (A), SW4.1
unnamed: D5.2 (A), SW5.1
unnamed: D6.2 (A), SW6.1
unnamed: D7.2 (A), SW7.1
unnamed: D8.2 (A), SW8.1
unnamed: D9.2 (A), SW9.1
unnamed: D10.2 (A), SW10.1
unnamed: NP1.4 (DOUT), NP6.2 (DIN)
unnamed: NP2.2 (DIN), NP7.4 (DOUT)
unnamed: NP2.4 (DOUT), NP3.2 (DIN)
unnamed: NP3.4 (DOUT), NP8.2 (DIN)
unnamed: NP4.2 (DIN), NP9.4 (DOUT)
unnamed: NP4.4 (DOUT), NP5.2 (DIN)
unnamed: NP6.4 (DOUT), NP7.2 (DIN)
unnamed: NP8.4 (DOUT), NP9.2 (DIN)
unnamed: NP5.4 (DOUT), NP10.2 (DIN)
unnamed: R2.2, U4.46 (USB_DM)
unnamed: R1.2, U4.47 (USB_DP)

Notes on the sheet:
Crystal
Make sure R1 and R2 are close to RP2040
Make sure C25 is close to pin 44 of RP2040
All NP parts are Xinglight XL-3528RGBW-WS2812B or equivalent (LCSC C2890364)
Make sure C24 is close to pin 45 of RP2040
Flash
Power

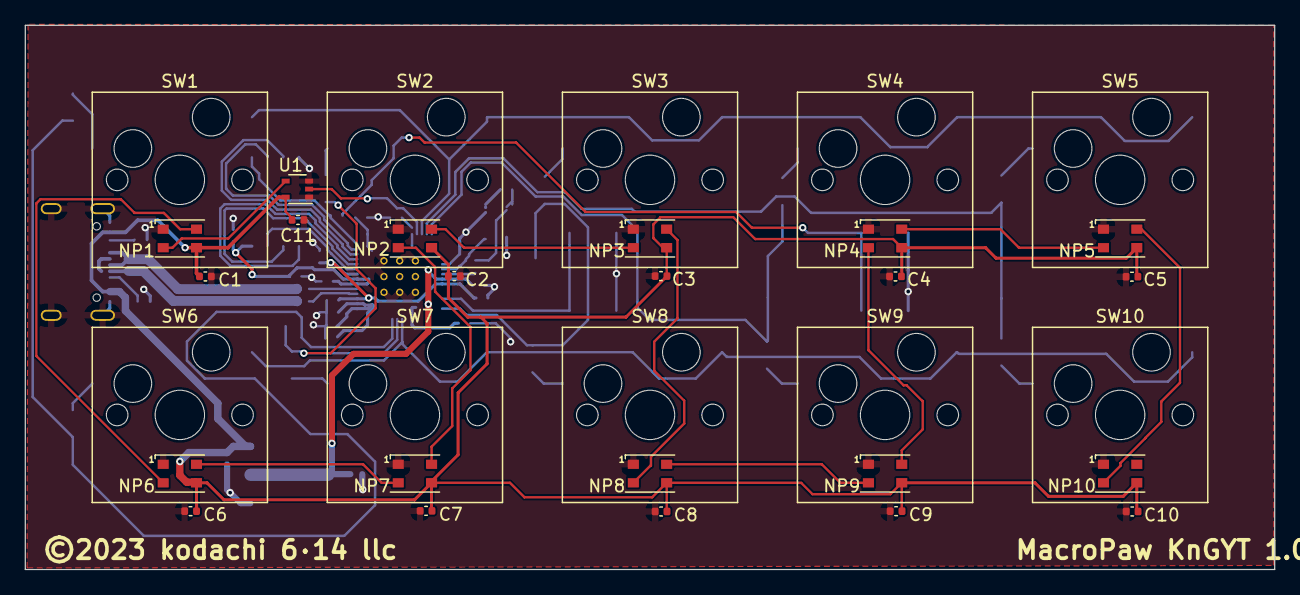
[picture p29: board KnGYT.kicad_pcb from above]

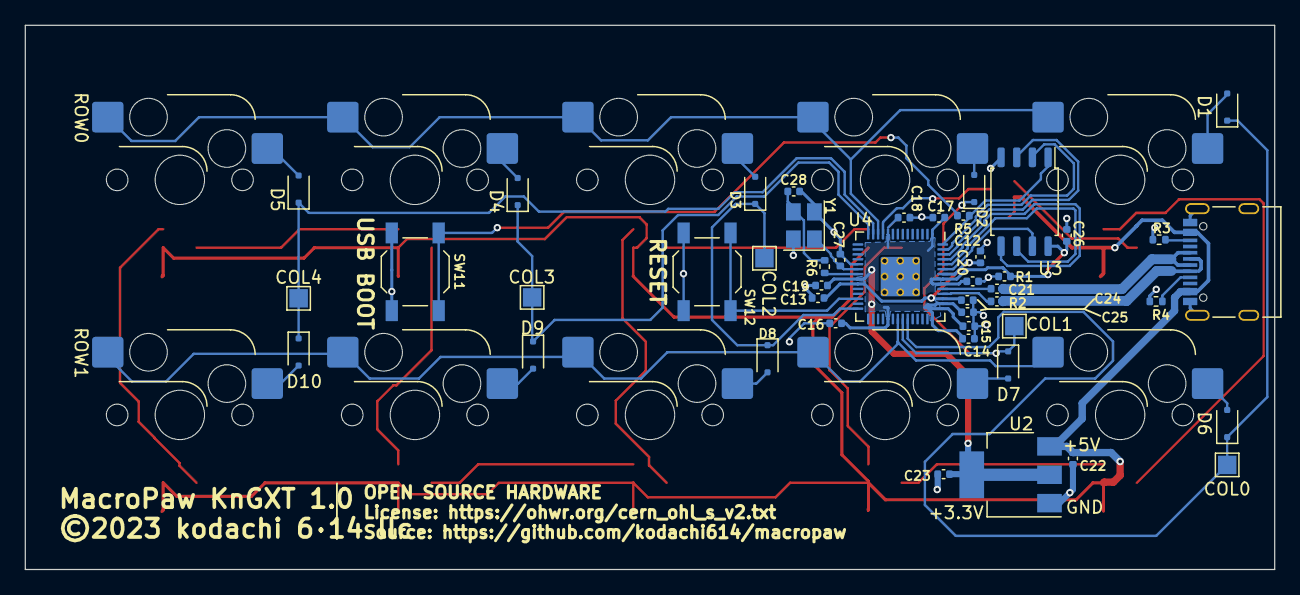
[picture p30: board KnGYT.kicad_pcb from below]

Board: 2 copper layers, 101.2 x 44.1 mm, 77 parts (55 on the bottom side), 49 nets.

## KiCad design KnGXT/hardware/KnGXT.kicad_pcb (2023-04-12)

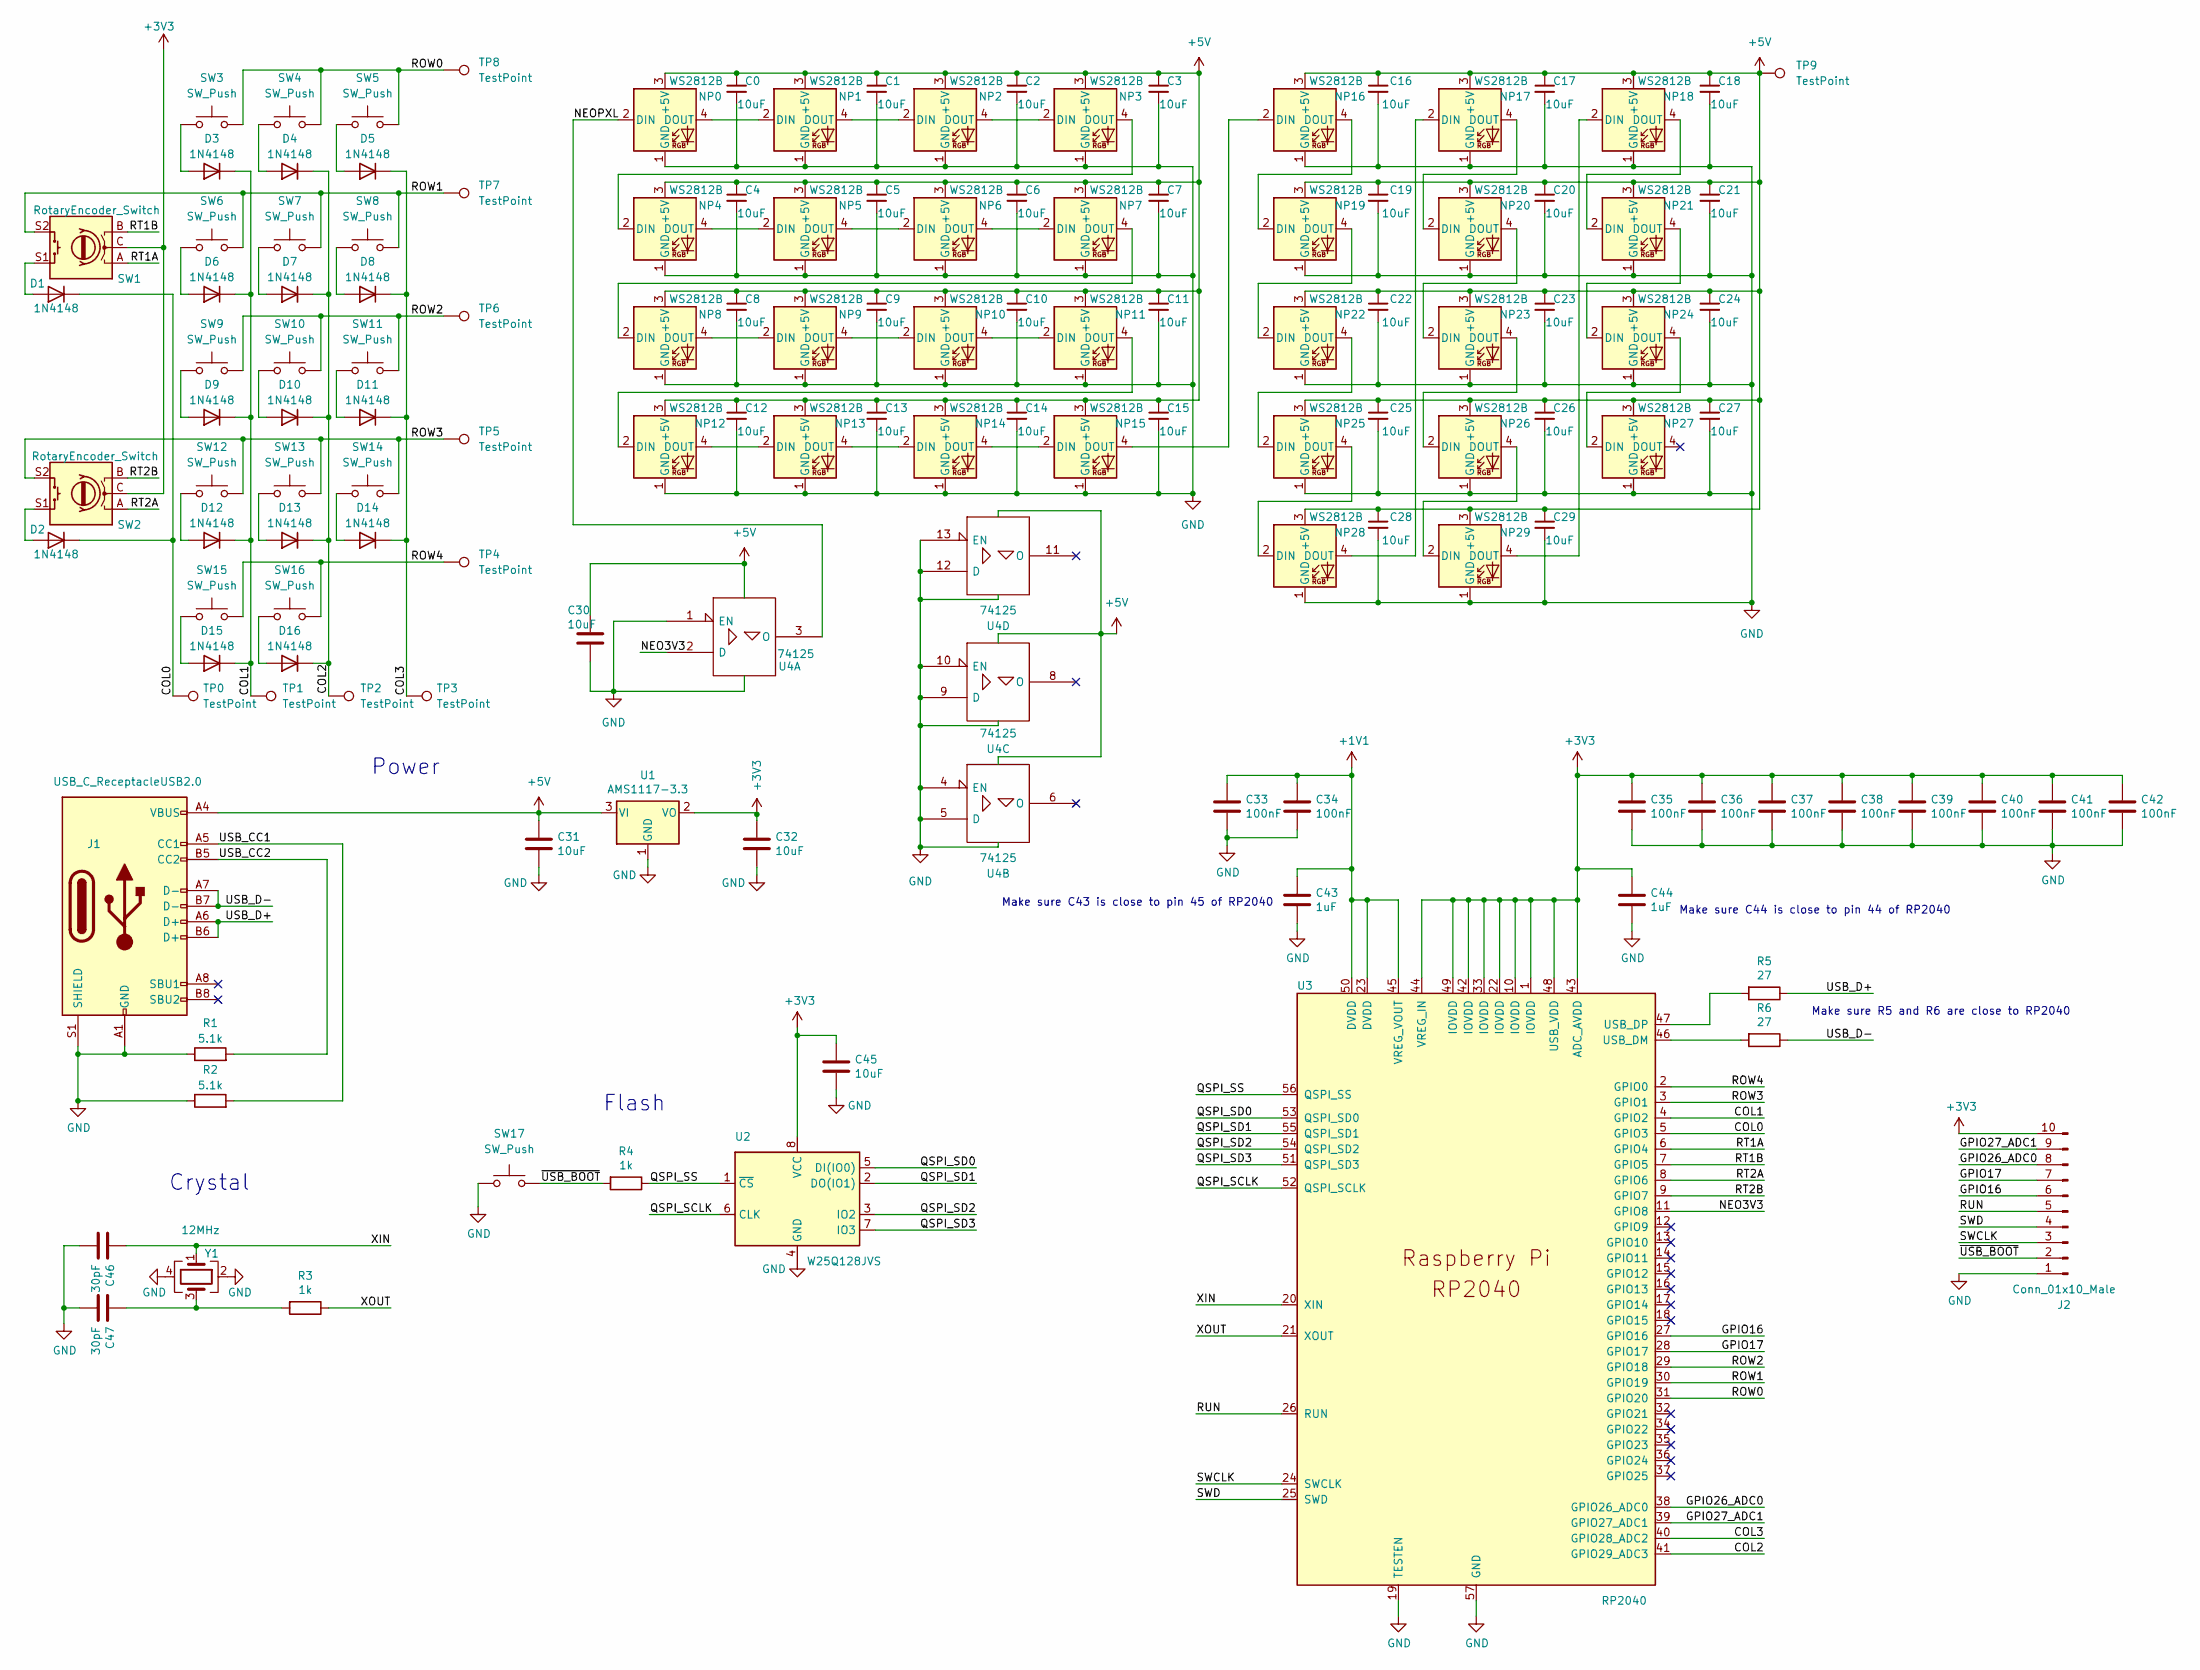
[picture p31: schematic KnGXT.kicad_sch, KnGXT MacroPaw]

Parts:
C0, C1, C2, C3, C4, C5, C6, C7, C8, C9, C10, C11, C12, C13, C14, C15, C16, C17, C18, C19, C20, C21, C22, C23, C24, C25, C26, C27, C28, C29, C30, C31, C32, C45: 10uF; C_0402_1005Metric; LCSC C15525
C33, C34, C35, C36, C37, C38, C39, C40, C41, C42: 100nF; C_0402_1005Metric; LCSC C1525
C43, C44: 1uF; C_0402_1005Metric; LCSC C52923
C46, C47: 30pF; C_0402_1005Metric; LCSC C1570
D1, D2, D3, D4, D5, D6, D7, D8, D9, D10, D11, D12, D13, D14, D15, D16: 1N4148; D_SOD-323F; LCSC C2128
J1: USB_C_ReceptacleUSB2.0; USB_C_Receptacle_Palconn_UTC16-G; LCSC C165948
J2: Conn_01x10_Male; PinHeader_1x10_P2.54mm_Horizontal
NP0, NP1, NP2, NP3, NP4, NP5, NP6, NP7, NP8, NP9, NP10, NP11, NP12, NP13, NP14, NP15, NP16, NP17, NP18, NP19, NP20, NP21, NP22, NP23, NP24, NP25, NP26, NP27, NP28, NP29: WS2812B; LED XL-3528RGBW-WS2812B (3.5x2.8, C2890364); LCSC C2890364
R1, R2: 5.1k; R_0402_1005Metric; LCSC C25905
R3: 1k; R_0402_1005Metric; LCSC C11702
R4: 1k; C_0402_1005Metric; LCSC C11702
R5, R6: 27; C_0402_1005Metric; LCSC C25100
SW1, SW2: RotaryEncoder_Switch; RotaryEncoder_Alps_EC12E-Switch_Vertical_H20mm
SW3, SW4, SW5, SW6, SW7, SW8, SW9, SW10, SW11, SW12, SW13, SW14, SW15: SW_Push; SW_Hotswap_Kailh_MX_1.00u
SW16: SW_Push; SW_Hotswap_Kailh_MX_2.00u
SW17: SW_Push; SW_SPST_TL3342; LCSC C318884
TP0, TP1, TP2, TP3, TP4, TP5, TP6, TP7, TP8, TP9: TestPoint; TestPoint_Loop_D1.80mm_Drill1.0mm_Beaded
U1: AMS1117-3.3; SOT-223-3_TabPin2; LCSC C6186
U2: W25Q128JVS; SOIC-8_5.23x5.23mm_P1.27mm; LCSC C97521
U3: RP2040; RP2040-QFN-56; LCSC C2040
U4: 74125; TSSOP-14_4.4x5mm_P0.65mm; LCSC C36365
Y1: 12MHz; Crystal_SMD_3225-4Pin_3.2x2.5mm; LCSC C9002

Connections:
+1V1: C33.1, C34.1, C43.1, U3.23 (DVDD), U3.45 (VREG_VOUT), U3.50 (DVDD)
+3V3: C32.1, C35.1, C36.1, C37.1, C38.1, C39.1, C40.1, C41.1, C42.1, C44.1, C45.1, J2.10, SW1.C, SW2.C, U1.2 (VO), U2.8 (VCC), U3.1 (IOVDD), U3.10 (IOVDD), U3.22 (IOVDD), U3.33 (IOVDD), U3.42 (IOVDD), U3.43 (ADC_AVDD), U3.44 (VREG_IN), U3.48 (USB_VDD), U3.49 (IOVDD)
+5V: C0.1, C1.1, C2.1, C3.1, C4.1, C5.1, C6.1, C7.1, C8.1, C9.1, C10.1, C11.1, C12.1, C13.1, C14.1, C15.1, C16.1, C17.1, C18.1, C19.1, C20.1, C21.1, C22.1, C23.1, C24.1, C25.1, C26.1, C27.1, C28.1, C29.1, C30.1, C31.1, J1.A4 (VBUS), J1.A9 (VBUS), J1.B4 (VBUS), J1.B9 (VBUS), NP0.3 (VDD), NP1.3 (+5V), NP2.3 (VDD), NP3.3 (VDD), NP4.3 (VDD), NP5.3 (VDD), NP6.3 (VDD), NP7.3 (VDD), NP8.3 (VDD), NP9.3 (VDD), NP10.3 (VDD), NP11.3 (VDD), NP12.3 (VDD), NP13.3 (VDD), NP14.3 (VDD), NP15.3 (VDD), NP16.3 (VDD), NP17.3 (VDD), NP18.3 (VDD), NP19.3 (VDD), NP20.3 (VDD), NP21.3 (VDD), NP22.3 (VDD), NP23.3 (VDD), NP24.3 (VDD), NP25.3 (VDD), NP26.3 (VDD), NP27.3 (VDD), NP28.3 (VDD), NP29.3 (VDD), TP9.1, U1.3 (VI), U4.14 (VCC); also elsewhere on the board
/COL0: D1.1 (K), D2.1 (K), TP0.1, U3.5 (GPIO3)
/COL1: D3.1 (K), D6.1 (K), D9.1 (K), D12.1 (K), D15.1 (K), TP1.1, U3.4 (GPIO2)
/COL2: D4.1 (K), D7.1 (K), D10.1 (K), D13.1 (K), D16.1 (K), TP2.1, U3.41 (GPIO29_ADC3)
/COL3: D5.1 (K), D8.1 (K), D11.1 (K), D14.1 (K), TP3.1, U3.40 (GPIO28_ADC2)
/GPIO16: J2.6, U3.27 (GPIO16)
/GPIO17: J2.7, U3.28 (GPIO17)
/GPIO26_ADC0: J2.8, U3.38 (GPIO26_ADC0)
/GPIO27_ADC1: J2.9, U3.39 (GPIO27_ADC1)
/NEO3V3: U3.11 (GPIO8), U4.2 (D)
/NEOPXL: NP0.2 (DIN), U4.3 (O)
/QSPI_SCLK: U2.6 (CLK), U3.52 (QSPI_SCLK)
/QSPI_SD0: U2.5 (DI(IO0)), U3.53 (QSPI_SD0)
/QSPI_SD1: U2.2 (DO(IO1)), U3.55 (QSPI_SD1)
/QSPI_SD2: U2.3 (IO2), U3.54 (QSPI_SD2)
/QSPI_SD3: U2.7 (IO3), U3.51 (QSPI_SD3)
/QSPI_SS: R4.1, U2.1 (~CS), U3.56 (QSPI_SS)
/ROW0: SW3.2, SW4.2, SW5.2, TP8.1, U3.31 (GPIO20)
/ROW1: SW1.S2, SW6.2, SW7.2, SW8.2, TP7.1, U3.30 (GPIO19)
/ROW2: SW9.2, SW10.2, SW11.2, TP6.1, U3.29 (GPIO18)
/ROW3: SW2.S2, SW12.2, SW13.2, SW14.2, TP5.1, U3.3 (GPIO1)
/ROW4: SW15.2, SW16.2, TP4.1, U3.2 (GPIO0)
/RT1A: SW1.A, U3.6 (GPIO4)
/RT1B: SW1.B, U3.7 (GPIO5)
/RT2A: SW2.A, U3.8 (GPIO6)
/RT2B: SW2.B, U3.9 (GPIO7)
/RUN: J2.5, U3.26 (RUN)
/SWCLK: J2.3, U3.24 (SWCLK)
/SWD: J2.4, U3.25 (SWD)
/USB_CC1: J1.A5 (CC1), R2.2
/USB_CC2: J1.B5 (CC2), R1.2
/USB_D+: J1.A6 (D+), J1.B6 (D+), R5.1
/USB_D-: J1.A7 (D-), J1.B7 (D-), R6.1
/XIN: C46.1, U3.20 (XIN), Y1.1
/XOUT: R3.1, U3.21 (XOUT)
/~USB_BOOT: J2.2, R4.2, SW17.2
GND: C0.2, C1.2, C2.2, C3.2, C4.2, C5.2, C6.2, C7.2, C8.2, C9.2, C10.2, C11.2, C12.2, C13.2, C14.2, C15.2, C16.2, C17.2, C18.2, C19.2, C20.2, C21.2, C22.2, C23.2, C24.2, C25.2, C26.2, C27.2, C28.2, C29.2, C30.2, C31.2, C32.2, C33.2, C34.2, C35.2, C36.2, C37.2, C38.2, C39.2, C40.2, C41.2, C42.2, C43.2, C44.2, C45.2, C46.2, C47.2, J1.A1 (GND), J1.A12 (GND), J1.B1 (GND), J1.B12 (GND), J1.S1 (SHIELD), J2.1, NP0.1 (VSS), NP1.1 (GND), NP2.1 (VSS), NP3.1 (VSS), NP4.1 (VSS), NP5.1 (VSS), NP6.1 (VSS), NP7.1 (VSS), NP8.1 (VSS), NP9.1 (VSS), NP10.1 (VSS), NP11.1 (VSS), NP12.1 (VSS), NP13.1 (VSS), NP14.1 (VSS), NP15.1 (VSS), NP16.1 (VSS), NP17.1 (VSS), NP18.1 (VSS), NP19.1 (VSS), NP20.1 (VSS), NP21.1 (VSS), NP22.1 (VSS), NP23.1 (VSS), NP24.1 (VSS), NP25.1 (VSS), NP26.1 (VSS), NP27.1 (VSS), NP28.1 (VSS), NP29.1 (VSS), R1.1, R2.1, SW17.1, U1.1 (GND), U2.4 (GND), U3.19 (TESTEN), U3.57 (GND), U4.1 (EN), U4.4 (EN), U4.5 (D), U4.7 (GND), U4.9 (D), U4.10 (EN), U4.12 (D), U4.13 (EN), Y1.2, Y1.4; also elsewhere on the board
unnamed: C47.1, R3.2, Y1.3
unnamed: D1.2 (A), SW1.S1
unnamed: D2.2 (A), SW2.S1
unnamed: D3.2 (A), SW3.1
unnamed: D4.2 (A), SW4.1
unnamed: D5.2 (A), SW5.1
unnamed: D6.2 (A), SW6.1
unnamed: D7.2 (A), SW7.1
unnamed: D8.2 (A), SW8.1
unnamed: D9.2 (A), SW9.1
unnamed: D10.2 (A), SW10.1
unnamed: D11.2 (A), SW11.1
unnamed: D12.2 (A), SW12.1
unnamed: D13.2 (A), SW13.1
unnamed: D14.2 (A), SW14.1
unnamed: D15.2 (A), SW15.1
unnamed: D16.2 (A), SW16.1
unnamed 56: NP0.4 (DOUT), NP1.2 (DIN); also elsewhere on the board
unnamed 57: NP1.4 (DOUT), NP2.2 (DIN); also elsewhere on the board
unnamed: NP2.4 (DOUT), NP3.2 (DIN)
unnamed: NP3.4 (DOUT), NP4.2 (DIN)
unnamed: NP4.4 (DOUT), NP5.2 (DIN)
unnamed: NP5.4 (DOUT), NP6.2 (DIN)
unnamed: NP6.4 (DOUT), NP7.2 (DIN)
unnamed: NP7.4 (DOUT), NP8.2 (DIN)
unnamed: NP8.4 (DOUT), NP9.2 (DIN)
unnamed: NP9.4 (DOUT), NP10.2 (DIN)
unnamed: NP10.4 (DOUT), NP11.2 (DIN)
unnamed: NP11.4 (DOUT), NP12.2 (DIN)
unnamed: NP12.4 (DOUT), NP13.2 (DIN)
unnamed: NP13.4 (DOUT), NP14.2 (DIN)
unnamed: NP14.4 (DOUT), NP15.2 (DIN)
unnamed: NP15.4 (DOUT), NP16.2 (DIN)
unnamed: NP16.4 (DOUT), NP19.2 (DIN)
unnamed: NP17.2 (DIN), NP28.4 (DOUT)
unnamed: NP17.4 (DOUT), NP20.2 (DIN)
unnamed: NP18.2 (DIN), NP29.4 (DOUT)
unnamed: NP18.4 (DOUT), NP21.2 (DIN)
unnamed: NP19.4 (DOUT), NP22.2 (DIN)
unnamed: NP20.4 (DOUT), NP23.2 (DIN)
unnamed: NP21.4 (DOUT), NP24.2 (DIN)
unnamed: NP22.4 (DOUT), NP25.2 (DIN)
unnamed: NP23.4 (DOUT), NP26.2 (DIN)
unnamed: NP24.4 (DOUT), NP27.2 (DIN)
unnamed: NP25.4 (DOUT), NP28.2 (DIN)
unnamed: NP26.4 (DOUT), NP29.2 (DIN)
unnamed: R5.2, U3.47 (USB_DP)
unnamed: R6.2, U3.46 (USB_DM)

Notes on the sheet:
Crystal
Make sure R5 and R6 are close to RP2040
Make sure C44 is close to pin 44 of RP2040
Make sure C43 is close to pin 45 of RP2040
Flash
Power

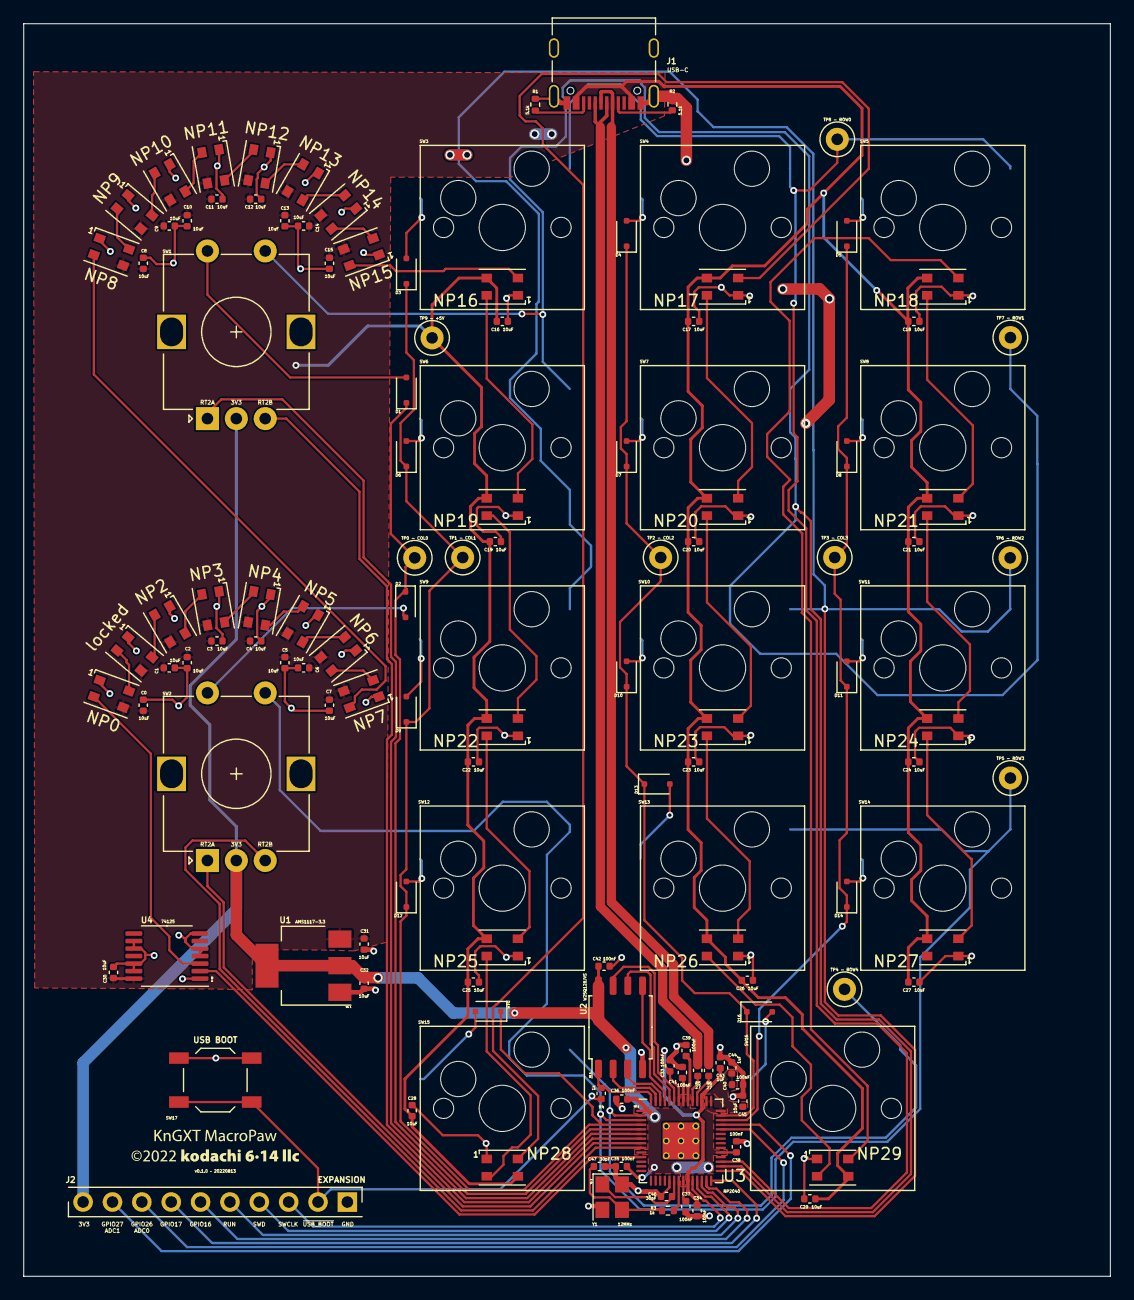
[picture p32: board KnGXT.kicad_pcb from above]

Board: 2 copper layers, 94.0 x 108.3 mm, 134 parts (0 on the bottom side), 87 nets.

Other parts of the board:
locked: WS2812B; LED XL-3528RGBW-WS2812B (3.5x2.8, C2890364)

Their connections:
+5V: locked.3 (VDD); also elsewhere on the board
GND: locked.1 (VSS); also elsewhere on the board
unnamed 56: locked.2 (DIN); also elsewhere on the board
unnamed 57: locked.4 (DOUT); also elsewhere on the board

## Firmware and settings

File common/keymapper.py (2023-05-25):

import storage

from kmk.keys import KC


class Keymapper:
    """
    Keymapper is meant to cope with the problem that the keycodes the
    MacroPaw sends need to change depending on what how the OS's keymap is
    set. For example, if the OS is using a QWERTY keymap and you want a key
    on the MacroPaw to type an E, you just send KC.E (code 8). But if the OS
    is using a Dvorak keymap, you need to send KC.D (code 7). This is because
    (to use Unicode terminology) the keycodes don't represent codepoints, they
    represent physical positions on the keyboard, even though they're ordered
    (basically) alphabetically (at least when you're talking about letters).
    So you have to send KC.D to get an E with the Dvorak map because the key
    you press to get an E when you use Dvorak is in the same position as the
    key you press to get a D when you use QWERTY.

    Horrible, isn't it? We need a real way to just send Unicode codepoints...
    and there isn't a standard way to do that.

    When using a Keymapper, you can use square brace or dot notation, the
    same as the KC class -- so Keymapper["SPACE"] and Keymapper.SPACE are
    both valid. You can also use the mapped() method if you need to have a
    Callable for some reason.
    """
    _map = {}

    def mapped(self, key):
        return KC[self._map.get(key, key)]

    def __getitem__(self, key):
        return self.mapped(key)

    def __getattr__(self, key):
        return self.mapped(key)

    @classmethod
    def switch_to(self, mappername):
        """
        Switch to a given Keymapper, assuming it exists!
        """

        if globals().get(mappername, None) is not None:
            try:
                storage.remount("/", readonly=False)
            except Exception as e:
                return (False, f"Error remounting / for writing: {e}")

            try:
                with open("/keymap", "w") as f:
                    f.write(mappername)
            except Exception as e:
                return (False, f"Error writing /keymap: {e}")

            try:
                storage.remount("/", readonly=True)
            except Exception as e:
                # We still return True here, because our caller should be
                # resetting the board.
                return (True, f"Error remounting / for reading: {e}")

            return(True, "OK")

        return (False, f"Keymapper {mappername} not found")


class _QWERTY(Keymapper):
    """
    The QWERTY Keymapper is just a passthrough, since QWERTY is the layout
    the keycodes are based on in the first place.
    """
    pass


QWERTY = _QWERTY()


class _Dvorak(Keymapper):
    """
    The Dvorak Keymapper maps keycodes you want into the keycodes you need to
    send when the OS is using the Dvorak layout.
    """
    _map = {
        'MINUS': r"'",
        'MINS': r"'",
        '-': r"'",

        'UNDERSCORE': r'"',
        'UNDS': r'"',
        '_': r'"',

        'EQUAL': r']',
        'EQL': r']',
        '=': r']',

        'PLUS': r'}',
        '+': r'}',

        'LBRACKET': r'-',
        'LBRC': r'-',
        '[': r'-',

        'LEFT_CURLY_BRACE': r'_',
        'LCBR': r'_',
        '{': r'_',

        'RBRACKET': r'=',
        'RBRC': r'=',
        ']': r'=',

        'RIGHT_CURLY_BRACE': r'+',
        'RCBR': r'+',
        '}': r'+',

        'COLON': r'Z',
        'COLN': r'Z',
        ':': r'Z',

        'SEMICOLON': r'z',
        'SCOLON': r'z',
        'SCLN': r'z',
        ';': r'z',

        'DOUBLE_QUOTE': r'Q',
        'DQUO': r'Q',
        'DQT': r'Q',
        '"': r'Q',

        'QUOTE': r'q',
        'QUOT': r'q',
        "'": r'q',

        'GRAVE': '`',
        'GRV': '`',
        'ZKHK': '`',
        '`': '`',

        'COMMA': r'w',
        'COMM': r'w',
        ',': r'w',

        'LEFT_ANGLE_BRACKET': r'W',
        'LABK': r'W',
        '<': r'W',

        'DOT': r'e',
        '.': r'e',

        'RIGHT_ANGLE_BRACKET': r'E',
        'RABK': r'E',
        '>': r'E',

        'QUESTION': r'{',
        'QUES': r'{',
        '?': r'{',

        'SLASH': r'[',
        'SLSH': r'[',
        '/': r'[',

        r'b': r'n',
        r'B': r'N',
        r'c': r'i',
        r'C': r'I',
        r'd': r'h',
        r'D': r'H',
        r'e': r'd',
        r'E': r'D',
        r'f': r'y',
        r'F': r'Y',
        r'g': r'u',
        r'G': r'U',
        r'h': r'j',
        r'H': r'J',
        r'i': r'g',
        r'I': r'G',
        r'j': r'c',
        r'J': r'C',
        r'k': r'v',
        r'K': r'V',
        r'l': r'p',
        r'L': r'P',
        r'n': r'l',
        r'N': r'L',
        r'o': r's',
        r'O': r'S',
        r'p': r'r',
        r'P': r'R',
        r'q': r'x',
        r'Q': r'X',
        r'r': r'o',
        r'R': r'O',
        r's': r';',
        r'S': r':',
        r't': r'k',
        r'T': r'K',
        r'u': r'f',
        r'U': r'F',
        r'x': r'b',
        r'X': r'B',
        r'y': r't',
        r'Y': r'T',
        r'z': r"/",
        r'Z': r'?',
    }

Dvorak = _Dvorak()


def _FSKeymapper():
    keymap = "QWERTY"

    try:
        keymap = open("/keymap", "r").readline().strip()
    except:
        keymap = "QWERTY"

    mapper = globals().get(keymap, QWERTY)

    return mapper

FSKeymapper = _FSKeymapper()


if __name__ == "__main__":
    mapper = Dvorak

    vectors = [
        [ [ "j", "J" ], "c", "C" ],
        [ [ "l", "L" ], "p", "P" ],
        [ [ " ", "SPACE" ], " ", "SPACE" ],
        [ [ "i", "I" ], "g", "G" ],
        [ [ "m", "M" ], "m", "M" ],
        [ [ "o", "O" ], "s", "S" ],
        [ [ "b", "B" ], "n", "N" ],
        [ [ "x", "X" ], "b", "B" ],
        [ [ "z" ], "/", "SLASH" ],
        [ [ "Z" ], "?", "QUESTION" ],
        [ [ "s" ], ";", "SCOLON" ],
        [ [ "S" ], ":", "COLON" ],
        [ [ ".", "DOT" ], "e", "E" ],
        [ [ "+", "PLUS" ], "}", "RIGHT_CURLY_BRACE" ],
        [ [ "=", "EQUAL" ], "]", "RBRACKET" ],
        [ [ "-", "MINUS" ], "'", "QUOTE" ],
        [ [ "/", "SLASH" ], "[", "LBRACKET" ],
        [ [ "*" ], "*" ],
        [ [ "LEFT" ], "LEFT" ],
        [ [ "RIGHT" ], "RIGHT" ],
    ]

    for vector in vectors:
        dv = vector[0]
        wanted = vector[1:]

        for i in dv:
            got1 = mapper[i]
            got2 = getattr(mapper, i)

            if got1 != got2:
                print(f"array/getattr failed for {i}: {got1} != {got2}")

            for w in wanted:
                got3 = KC[w]

                if got1 != got3:
                    print(f"dv/qw failed for {i} and {w}: {got1} != {got3}")

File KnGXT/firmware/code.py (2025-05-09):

# SPDX-FileCopyrightText: 2022 Kodachi 6 14
# SPDX-License-Identifier: GPL-3.0-or-later
#
# Copyright 2022 Kodachi 6 14
#
# This file is part of the MacroPaw firmware.
#
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
import supervisor

boot_time = supervisor.ticks_ms()

from kmk.extensions.rgb import AnimationModes
# from kmk.modules.usb_disconnect import USBDisconnect
from kmk.modules.layers import Layers as _Layers
from kmk.modules.holdtap import HoldTap

from macropaw import log_time

log_time(f"code.py start", boot_time)
log_time(f"code.py imports done")

#### USE THIS TO PICK YOUR KEYMAP ####
# An annoying thing about keyboards is that you have to match up with
# the keymap being used on the OS side. We look at the "/keymap" file
# to choose a Keymapper ("QWERTY" or "Dvorak") from keymapper.py. If
# the file isn't present or has an invalid map, we default to QWERTY.
#
# You can define your own in keymapper.py if you want to.

from keymapper import FSKeymapper as KC

log_time(f"import FSKeymapper (got {KC.__class__.__name__})")

# Layers is here to change the LED matrix color depending on what layer
# is active. This isn't necessarily the best way to do this, mind you.
class Layers(_Layers):
    last_top_layer = 0
    hues = [128, 0, 64, 96]
    rgb = None

    def after_hid_send(self, kbd):
        if self.rgb is not None:
            if kbd.active_layers[0] != self.last_top_layer:
                self.last_top_layer = kbd.active_layers[0]
                self.rgb.hue = self.hues[self.last_top_layer]


def setup_macropaw(debug, kbd):
    ring_color = (0, 0, 64) if debug.enabled else (0, 64, 0)
    kbd.setup_animation(ring_color=ring_color,
                        animation_mode=AnimationModes.USER,
                        hue_default=128,
                        animation_speed=4)
    kbd.setup_mapswitchers()

    layers = Layers()
    layers.rgb = kbd.rgb_matrix

    kbd.modules.append(HoldTap())
    kbd.modules.append(layers)
    # kbd.modules.append(USBDisconnect())

    # DaVinci Resolve keybindings
    key_PrevMark = KC.LSFT(KC.UP)
    key_NextMark = KC.LSFT(KC.DOWN)
    key_PrevEdit = KC.UP
    key_NextEdit = KC.DOWN
    key_PlayReverse = KC.J
    key_PlayForward = KC.L
    key_PlayPause = KC.SPACE
    key_MarkIn = KC.I
    key_Mark = KC.M
    key_MarkOut = KC.O
    key_Razor = KC.LGUI(KC.B)
    key_RippleDelete = KC.LSFT(KC.LGUI(KC.X))
    key_Cut = KC.LGUI(KC.X)
    key_PrevFrame = KC.LEFT
    key_NextFrame = KC.RIGHT
    key_Undo = KC.LGUI(KC.Z)
    key_Redo = KC.LSFT(KC.LGUI(KC.Z))
    key_Save = KC.LGUI(KC.S)

    key_PlusMinus = KC.HT(KC.PLUS, KC.MINUS)
    key_StarSlash = KC.HT(KC.ASTERISK, KC.SLASH)
    key_PeriodEqual = KC.HT(KC.DOT, KC.EQUAL)
    key_SevenOrParen = KC.HT(KC.N7, KC.LEFT_PAREN)
    key_NineOrParen = KC.HT(KC.N9, KC.RIGHT_PAREN)
    key_EightOrBS = KC.HT(KC.N8, KC.BSPC)

    kbd.keymap = [
        # 0: Main layer (default)
        [
            # Encoders: CCW, CW, button
            kbd.KeyVolDown,     kbd.KeyVolUp,     kbd.KeyMute,
            kbd.KeyPrevTrack,   kbd.KeyNextTrack, kbd.KeyPlay,

            # Main key matrix
            KC.F1,              KC.F2,            KC.F3,
            KC.F4,              KC.F5,            KC.F6,
            KC.F7,              KC.F8,            KC.F9,
            KC.F10,             KC.SPACE,         KC.ENTER,
            KC.F13,                KC.LT(1, KC.F14),
        ],

        # 1: Meta layer
        [
            # Encoders: CCW, CW, button
            KC.NO,              KC.NO,            KC.NO,
            KC.NO,              KC.NO,            KC.NO,

            # Main key matrix
            kbd.SwitchToQWERTY, KC.NO,            kbd.SwitchToDvorak,
            KC.NO,              KC.NO,            KC.NO,
            KC.NO,              KC.NO,            KC.NO,
            KC.TO(2),           KC.TO(3),         KC.NO,
            KC.TO(0),              KC.NO,
        ],

        # 2: DaVinci Resolve layer
        [
            # Encoders: CCW, CW, button
            key_PrevMark,       key_NextMark,     key_Mark,
            key_PlayReverse,    key_PlayForward,  key_PlayPause,

            # Main key matrix
            key_PrevEdit,       key_Mark,         key_NextEdit,
            key_Razor,          key_RippleDelete, key_Cut,
            key_PrevFrame,      key_MarkIn,       key_NextFrame,
            key_Undo,           key_MarkOut,      key_Redo,
            KC.NO,                 KC.LT(1, key_Save),
        ],

        # 3: Number pad layer
        [
            # Encoders: CCW, CW, button
            kbd.KeyVolDown,     kbd.KeyVolUp,     kbd.KeyMute,
            kbd.KeyPrevTrack,   kbd.KeyNextTrack, kbd.KeyPlay,

            # Main key matrix
            key_SevenOrParen,   key_EightOrBS,    key_NineOrParen,
            KC.N4,              KC.N5,            KC.N6,
            KC.N1,              KC.N2,            KC.N3,
            key_PeriodEqual,    KC.N0,            key_StarSlash,
            key_PlusMinus,         KC.LT(1, KC.ENTER),
        ]
    ]


if __name__ == '__main__':
    log_time("main start")

    from macropaw import Main

    log_time("import Main")

    Main(__name__, setup_macropaw)

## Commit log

2022-08-13 Don't track ZIPfiles
2022-08-13 Update the world to switch to 3.5x2.8mm WS2812B LEDs
    [KnGXT.kicad_pcb, KnGXT.kicad_sch]
2022-08-14 Swap the WS2812B _AGAIN_ since the C965557 is out of stock
    Thankfully the C2890364 is identical to the C965557, just
    rotated 180 degrees.
    [KnGXT.kicad_pcb, KnGXT.kicad_sch]
2022-08-14 Add version number
    [KnGXT.kicad_pcb]
2022-08-14 v0.1.0 fabrication outputs
    [KnGXT-BOM.csv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]
2022-08-14 Try reformatting the BOM and CPL (including CRLF instead of just LF)
    [KnGXT-BOM.csv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]
2022-09-05 Move hardware files to hardware/ directory
    [KnGXT-BOM.csv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]
2022-09-07 Update version, date, and license in schematic
    [KnGXT.kicad_sch]
2022-10-03 Have a directory per board model.
    [KnGXT-BOM.csv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]
2022-10-10 Add KiCad libraries
2023-04-02 Toss old kicad-libraries dir in favor of the kodachi614/kicadlib repo
2023-04-12 Whitespace fixes for KnGXT
    [boot.py, code.py, hardwaretest.py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]
2023-04-12 Update KnGXT boot stack & status-LED brightness
2023-04-12 USBDisconnect, not Power
2023-04-12 (Mostly?) update KnGXT for KiCad 7 and to use kicadlib.
    KnGXT probably still needs work to pass ERC & DRC, but that's OK because any new spin of it will make further changes.
    [KnGXT.kicad_pcb, KnGXT.kicad_sch]
2023-04-12 Commit STLs for KnGXT case model
    [Case Bottom.stl, Case Top with Boot Button.stl, Case Top with Boot Hole.stl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]
2023-04-12 Add Fusion 360 source for KnGXT case model
    [MacroPaw KnGXT.f3d]
2023-04-12 New MacroPaw KnGYT hardware!
    The KnGYT is a 5x2 minimalist layout. It's really a test of doublesided assembly.
    [KnGYT-B_Cu.gbr, KnGYT-B_Mask.gbr, KnGYT-B_Paste.gbr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]
2023-04-12 When building firmware, have the board run the hardware test on first boot.
2023-04-12 Switch to (hackily) versioned link for KnGXT firmware.
2023-05-25 Make hardware test stick until all the switches have been cycled through all their LED colors. Include a dim white in the initial colors.
2023-05-25 Include DaVinci Resolve and numpad layers.
    [code.py]
2023-05-25 Allow switching keymaps using keys.
2025-04-21 Initial Beatboxer (KnH0F) cut
    [Bottom.stl, End Cap.stl, KnH0F.kicad_pcb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]
2025-05-06 Define (and switch to) the breathmap effect.
2025-05-06 Drop ringrgb.py from KnGYT (it has no LED rings)
2025-05-06 KnGYT case models
    [Bottom.stl, End Cap.stl, Plate.stl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]
2025-05-07 Shouldn't have committed these models in the first place – they're for the KnGYT.
    (So is the firmware, for that matter. Sigh.)
    [Bottom.stl, End Cap.stl, Plate.stl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]
2025-05-07 BeatBoxer hardware as fabbed
    [KnH0F-BOM.csv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]
2025-05-07 CircuitPython stopped supporting setting the stack limit in either 9.x or 10.x.
2025-05-07 Update adafruit_pioasm.mpy to the CircuitPython 9 version
2025-05-07 Give PixelSlice a deinit method to avoid an error when it's used as an underlying pixel buffer for the KMK RGB extension
    [pixelslice.py]
2025-05-07 Port KnGYT to CircuitPython 9.2.7.
2025-05-08 Update CircuitPython and KMK versions in Makefile
2025-05-08 Write a README into the firmware telling what kind of board the firmware is for, and where to find the source.
2025-05-15 Use the HWTEST button for both mass storage mode and hardware test on the Beatboxer KnH0F.

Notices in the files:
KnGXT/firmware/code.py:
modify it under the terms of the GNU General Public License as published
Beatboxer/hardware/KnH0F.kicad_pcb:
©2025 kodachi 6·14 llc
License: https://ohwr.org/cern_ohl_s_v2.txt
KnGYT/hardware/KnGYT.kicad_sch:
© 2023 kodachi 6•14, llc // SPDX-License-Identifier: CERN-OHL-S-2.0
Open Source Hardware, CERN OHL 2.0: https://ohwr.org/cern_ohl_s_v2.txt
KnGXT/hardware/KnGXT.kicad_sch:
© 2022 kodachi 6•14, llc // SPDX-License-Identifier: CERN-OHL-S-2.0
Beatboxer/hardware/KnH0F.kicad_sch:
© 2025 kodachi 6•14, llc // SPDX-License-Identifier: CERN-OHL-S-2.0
